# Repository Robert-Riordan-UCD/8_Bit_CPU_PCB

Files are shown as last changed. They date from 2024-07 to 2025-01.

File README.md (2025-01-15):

# 8-Bit PCB CPU

This is my version of [Ben Eaters 8-bit breadboard SAP-1 CPU](https://eater.net/8bit), converted to a PCB. I have made some minor changes as I could not find all of the components as listed in Ben's part list.

## Video of the computer running
https://youtube.com/shorts/QNcSWgcGv9o?si=QzoUVq9Kj8X1f4Rs

## Major Changes

### Random Access Memory

1. RAM IC's have been replaced with ATMega328-PU's. This should allow me to have persistant programs between power cycles.

## License

CERN Open Hardware Licence Version 2 - Permissive

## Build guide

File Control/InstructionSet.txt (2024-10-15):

0000 - NO OP
0001 - LDA
0010 - STA
0011 - LDB
0100 - ADD
0101 - SUB
0110 - JMP
0111 - JMPC
1000 - JMPZ
1001 - NO OP
1010 - NO OP
1011 - NO OP
1100 - NO OP
1101 - NO OP
1110 - OUT
1111 - HALT

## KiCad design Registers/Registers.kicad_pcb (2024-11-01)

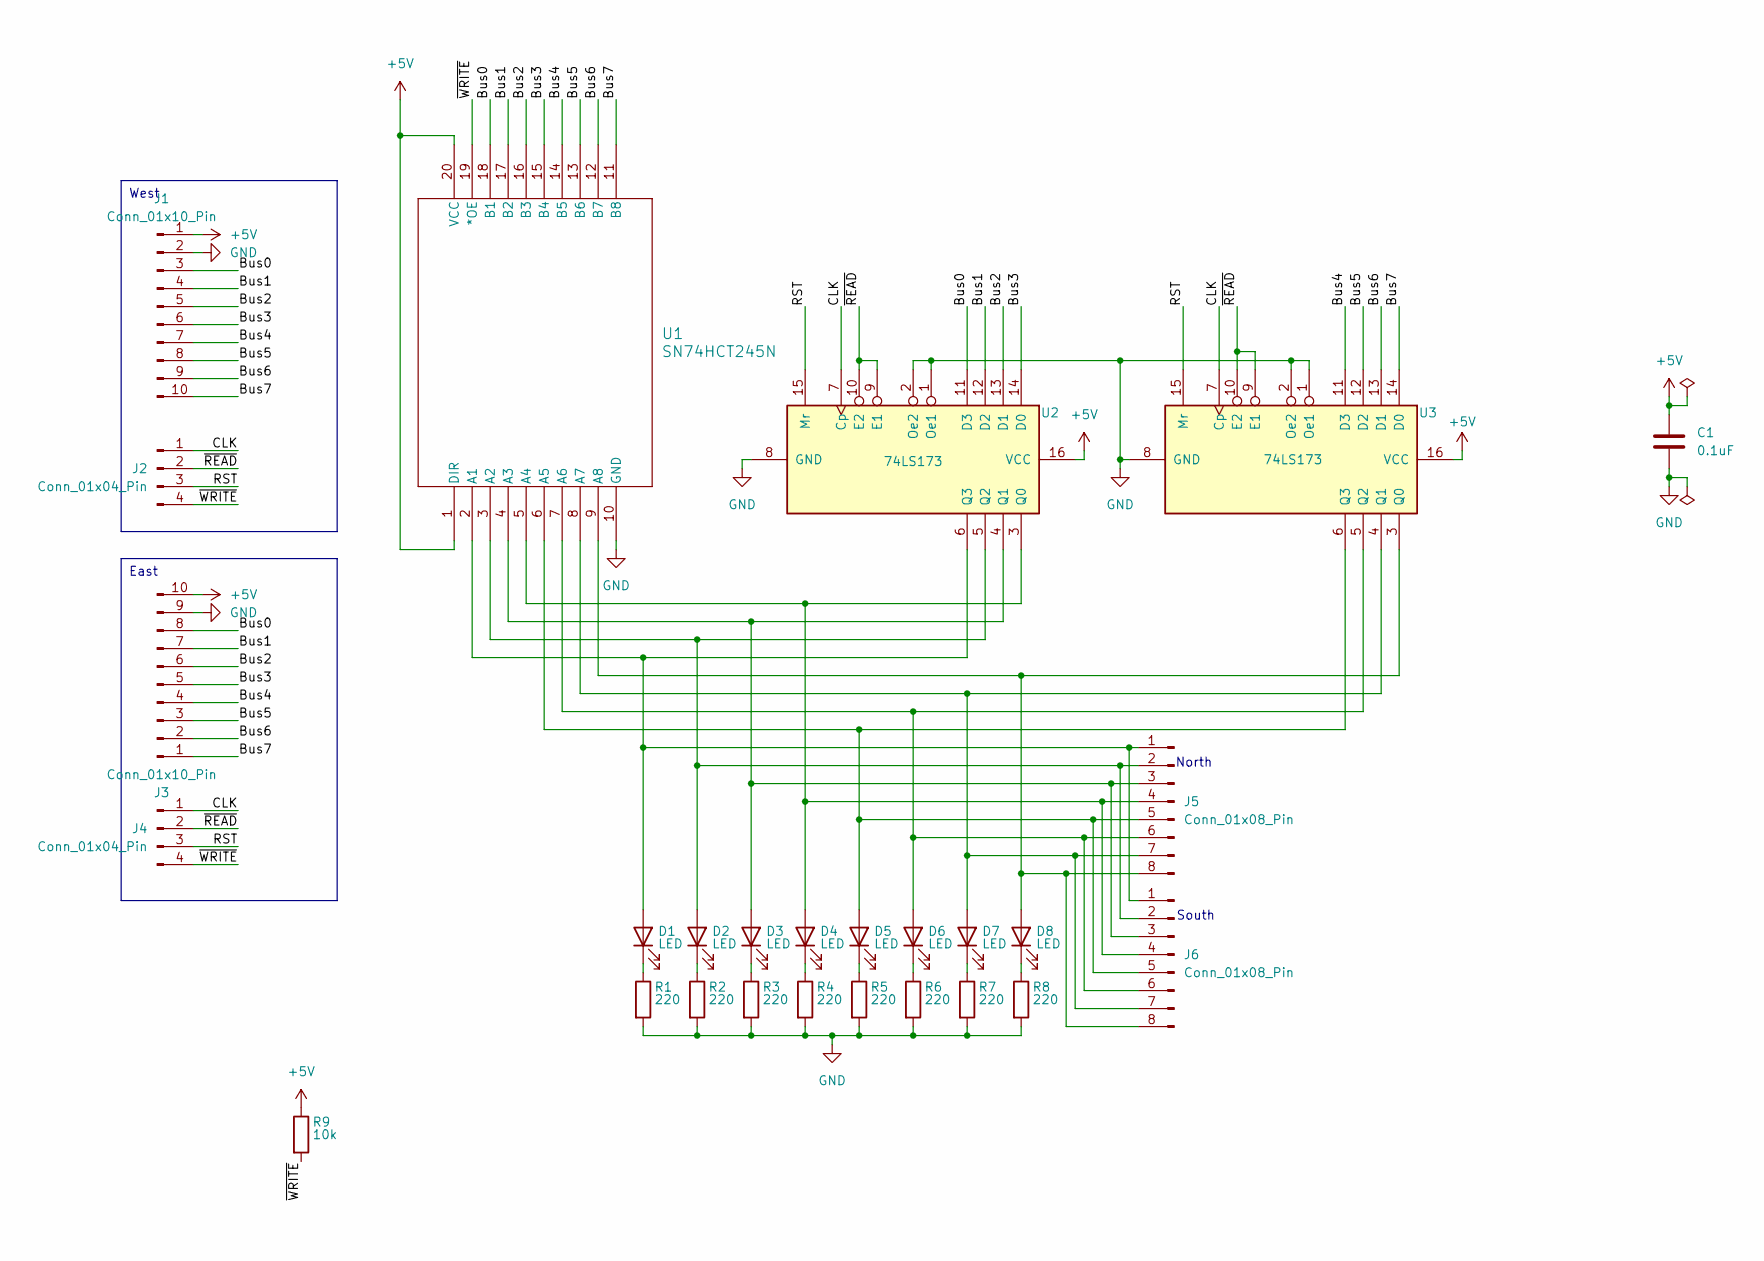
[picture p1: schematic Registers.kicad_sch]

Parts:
C1: 0.1uF; C_Disc_D5.0mm_W2.5mm_P2.50mm
D1, D2, D3, D4, D5, D6, D7, D8: LED; LED_D5.0mm
J1, J3: Conn_01x10_Pin; PinHeader_1x10_P2.54mm_Vertical
J2, J4: Conn_01x04_Pin; PinHeader_1x04_P2.54mm_Vertical
J5, J6: Conn_01x08_Pin; PinHeader_1x08_P2.54mm_Vertical
R1, R2, R3, R4, R5, R6, R7, R8: 220; CF_series_Resistors_THT
R9: 10k; CF_series_Resistors_THT
U1: SN74HCT245N; 8x_tristate_transceiver
U2, U3: 74LS173; DIP-16_W7.62mm

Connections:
+5V: C1.1, J1.1, J3.10, R9.1, U1.1 (DIR), U1.20 (VCC), U2.16 (VCC), U3.16 (VCC)
/Bus0: J1.3, J3.8, U1.18 (B1), U2.11 (D3)
/Bus1: J1.4, J3.7, U1.17 (B2), U2.12 (D2)
/Bus2: J1.5, J3.6, U1.16 (B3), U2.13 (D1)
/Bus3: J1.6, J3.5, U1.15 (B4), U2.14 (D0)
/Bus4: J1.7, J3.4, U1.14 (B5), U3.11 (D3)
/Bus5: J1.8, J3.3, U1.13 (B6), U3.12 (D2)
/Bus6: J1.9, J3.2, U1.12 (B7), U3.13 (D1)
/Bus7: J1.10, J3.1, U1.11 (B8), U3.14 (D0)
/CLK: J2.1, J4.1, U2.7 (Cp), U3.7 (Cp)
/RST: J2.3, J4.3, U2.15 (Mr), U3.15 (Mr)
/~READ: J2.2, J4.2, U2.9 (E1), U2.10 (E2), U3.9 (E1), U3.10 (E2)
/~WRITE: J2.4, J4.4, R9.2, U1.19 (*OE)
GND: C1.2, J1.2, J3.9, R1.2, R2.2, R3.2, R4.2, R5.2, R6.2, R7.2, R8.2, U1.10 (GND), U2.1 (Oe1), U2.2 (Oe2), U2.8 (GND), U3.1 (Oe1), U3.2 (Oe2), U3.8 (GND)
unnamed: D1.2 (A), J5.1, J6.1, U1.2 (A1), U2.6 (Q3)
unnamed: D1.1 (K), R1.1
unnamed: D2.2 (A), J5.2, J6.2, U1.3 (A2), U2.5 (Q2)
unnamed: D2.1 (K), R2.1
unnamed: D3.2 (A), J5.3, J6.3, U1.4 (A3), U2.4 (Q1)
unnamed: D3.1 (K), R3.1
unnamed: D4.2 (A), J5.4, J6.4, U1.5 (A4), U2.3 (Q0)
unnamed: D4.1 (K), R4.1
unnamed: D5.2 (A), J5.5, J6.5, U1.6 (A5), U3.6 (Q3)
unnamed: D5.1 (K), R5.1
unnamed: D6.2 (A), J5.6, J6.6, U1.7 (A6), U3.5 (Q2)
unnamed: D6.1 (K), R6.1
unnamed: D7.2 (A), J5.7, J6.7, U1.8 (A7), U3.4 (Q1)
unnamed: D7.1 (K), R7.1
unnamed: D8.2 (A), J5.8, J6.8, U1.9 (A8), U3.3 (Q0)
unnamed: D8.1 (K), R8.1

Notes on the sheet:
West
East
North
South

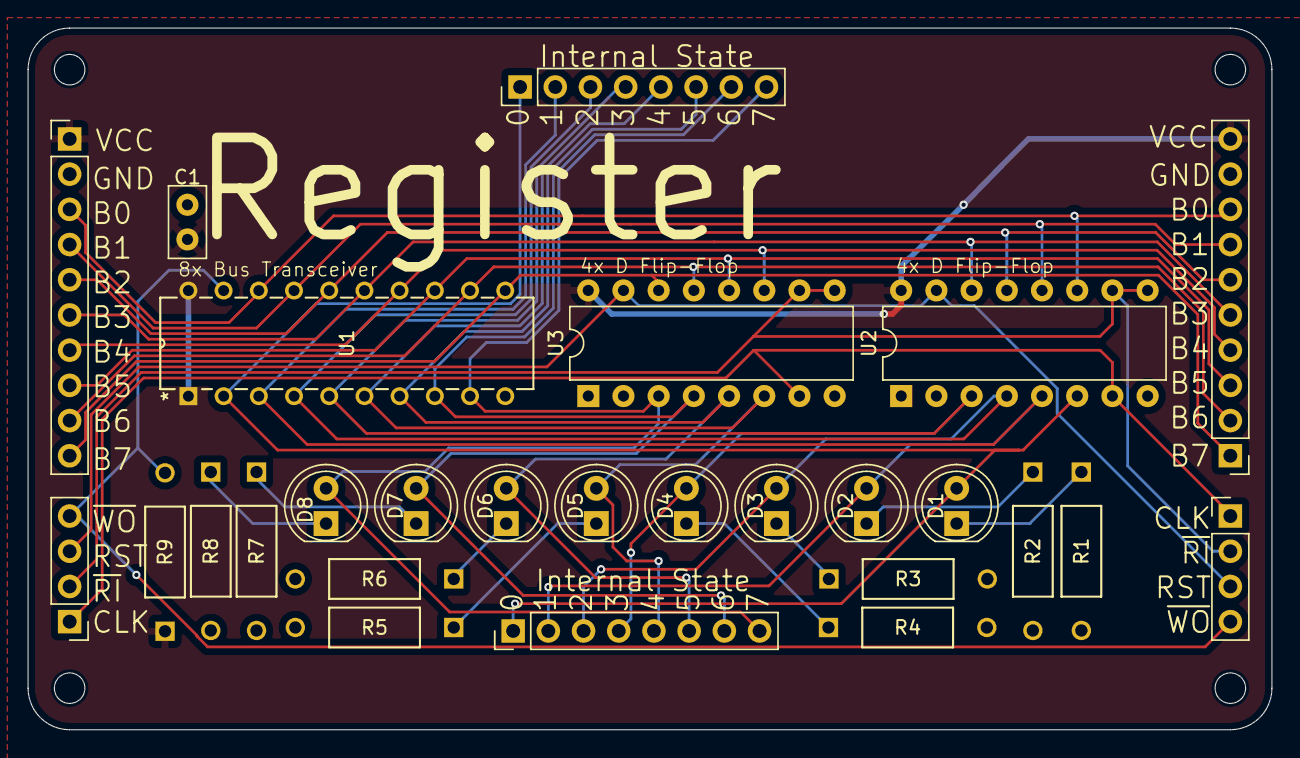
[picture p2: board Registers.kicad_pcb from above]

Board: 2 copper layers, 89.8 x 50.6 mm, 27 parts (0 on the bottom side), 30 nets.

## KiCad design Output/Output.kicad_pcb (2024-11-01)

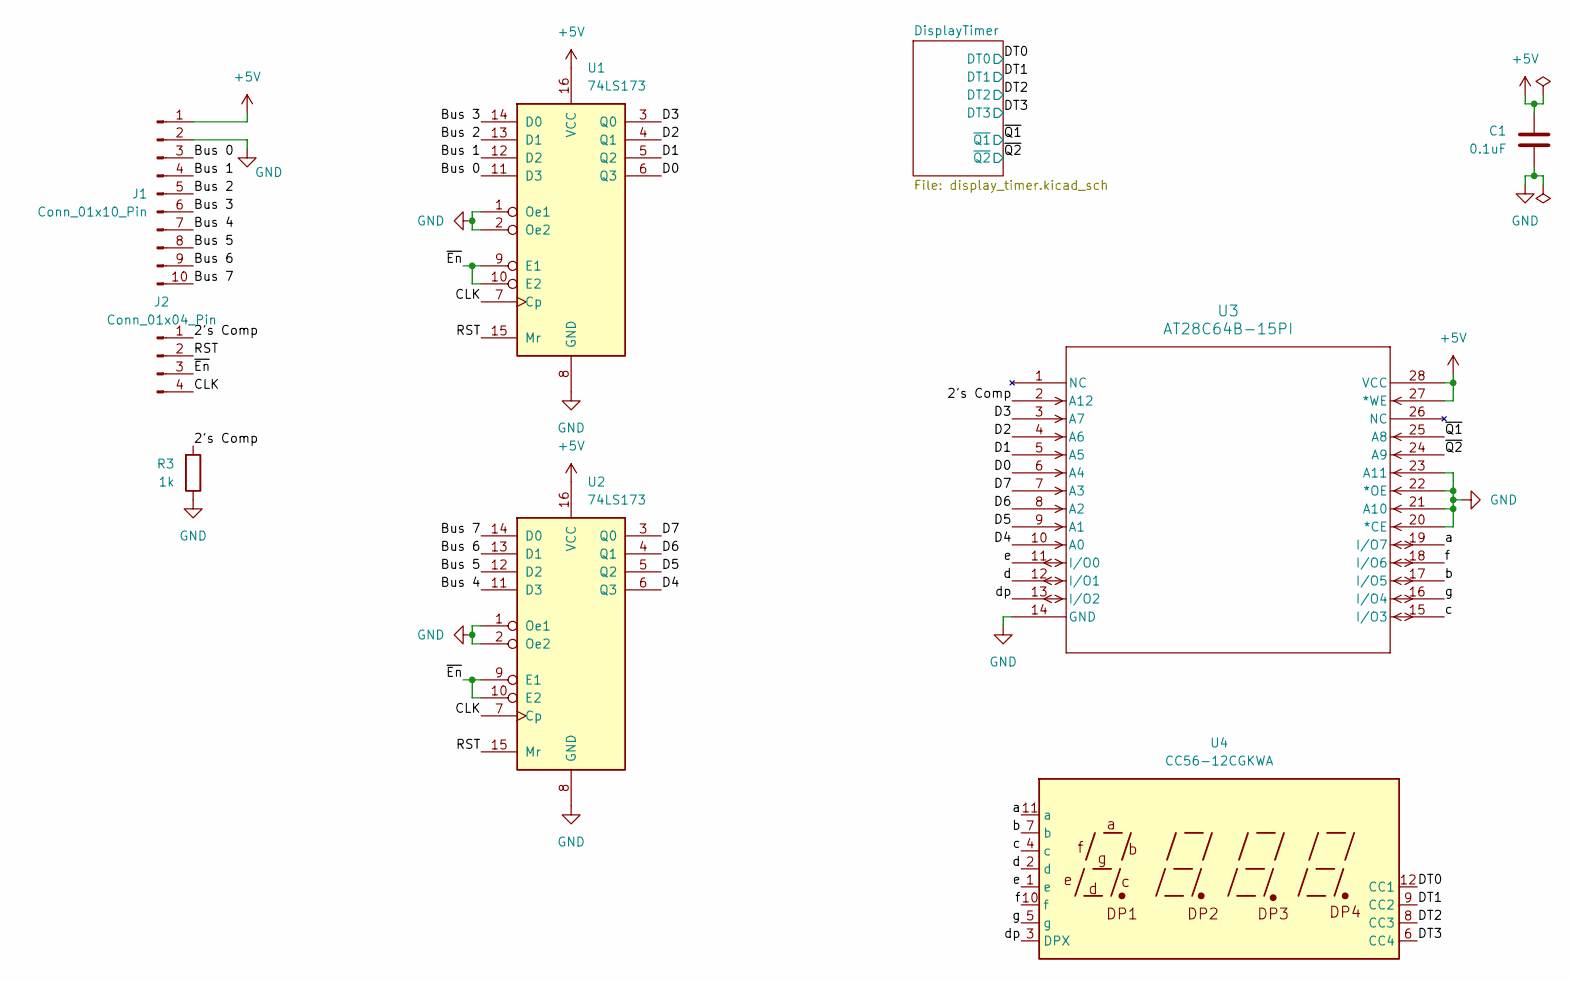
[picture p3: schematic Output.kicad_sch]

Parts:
C1: 0.1uF; C_Disc_D5.0mm_W2.5mm_P2.50mm
J1: Conn_01x10_Pin; PinHeader_1x10_P2.54mm_Vertical
J2: Conn_01x04_Pin; PinHeader_1x04_P2.54mm_Vertical
R3: 1k; CF_series_Resistors_THT
U1, U2: 74LS173; DIP-16_W7.62mm
U3: AT28C64B-15PI; eeprom
U4: CC56-12CGKWA; CA56-12CGKWA

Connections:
+5V: C1.1, J1.1, U1.16 (VCC), U2.16 (VCC), U3.27 (*WE), U3.28 (VCC); also elsewhere on the board
/2's Comp: J2.1, R3.2, U3.2 (A12)
/Bus 0: J1.3, U1.11 (D3)
/Bus 1: J1.4, U1.12 (D2)
/Bus 2: J1.5, U1.13 (D1)
/Bus 3: J1.6, U1.14 (D0)
/Bus 4: J1.7, U2.11 (D3)
/Bus 5: J1.8, U2.12 (D2)
/Bus 6: J1.9, U2.13 (D1)
/Bus 7: J1.10, U2.14 (D0)
/CLK: J2.4, U1.7 (Cp), U2.7 (Cp)
/D0: U1.6 (Q3), U3.6 (A4)
/D1: U1.5 (Q2), U3.5 (A5)
/D2: U1.4 (Q1), U3.4 (A6)
/D3: U1.3 (Q0), U3.3 (A7)
/D4: U2.6 (Q3), U3.10 (A0)
/D5: U2.5 (Q2), U3.9 (A1)
/D6: U2.4 (Q1), U3.8 (A2)
/D7: U2.3 (Q0), U3.7 (A3)
/DT0: U4.12 (CC1); also elsewhere on the board
/DT1: U4.9 (CC2); also elsewhere on the board
/DT2: U4.8 (CC3); also elsewhere on the board
/DT3: U4.6 (CC4); also elsewhere on the board
/RST: J2.2, U1.15 (Mr), U2.15 (Mr)
/a: U3.19 (I/O7), U4.11 (a)
/b: U3.17 (I/O5), U4.7 (b)
/c: U3.15 (I/O3), U4.4 (c)
/d: U3.12 (I/O1), U4.2 (d)
/dp: U3.13 (I/O2), U4.3 (DPX)
/e: U3.11 (I/O0), U4.1 (e)
/f: U3.18 (I/O6), U4.10 (f)
/g: U3.16 (I/O4), U4.5 (g)
/~En: J2.3, U1.9 (E1), U1.10 (E2), U2.9 (E1), U2.10 (E2)
/~Q1: U3.25 (A8); also elsewhere on the board
/~Q2: U3.24 (A9); also elsewhere on the board
GND: C1.2, J1.2, R3.1, U1.1 (Oe1), U1.2 (Oe2), U1.8 (GND), U2.1 (Oe1), U2.2 (Oe2), U2.8 (GND), U3.14 (GND), U3.20 (*CE), U3.21 (A10), U3.22 (*OE), U3.23 (A11); also elsewhere on the board

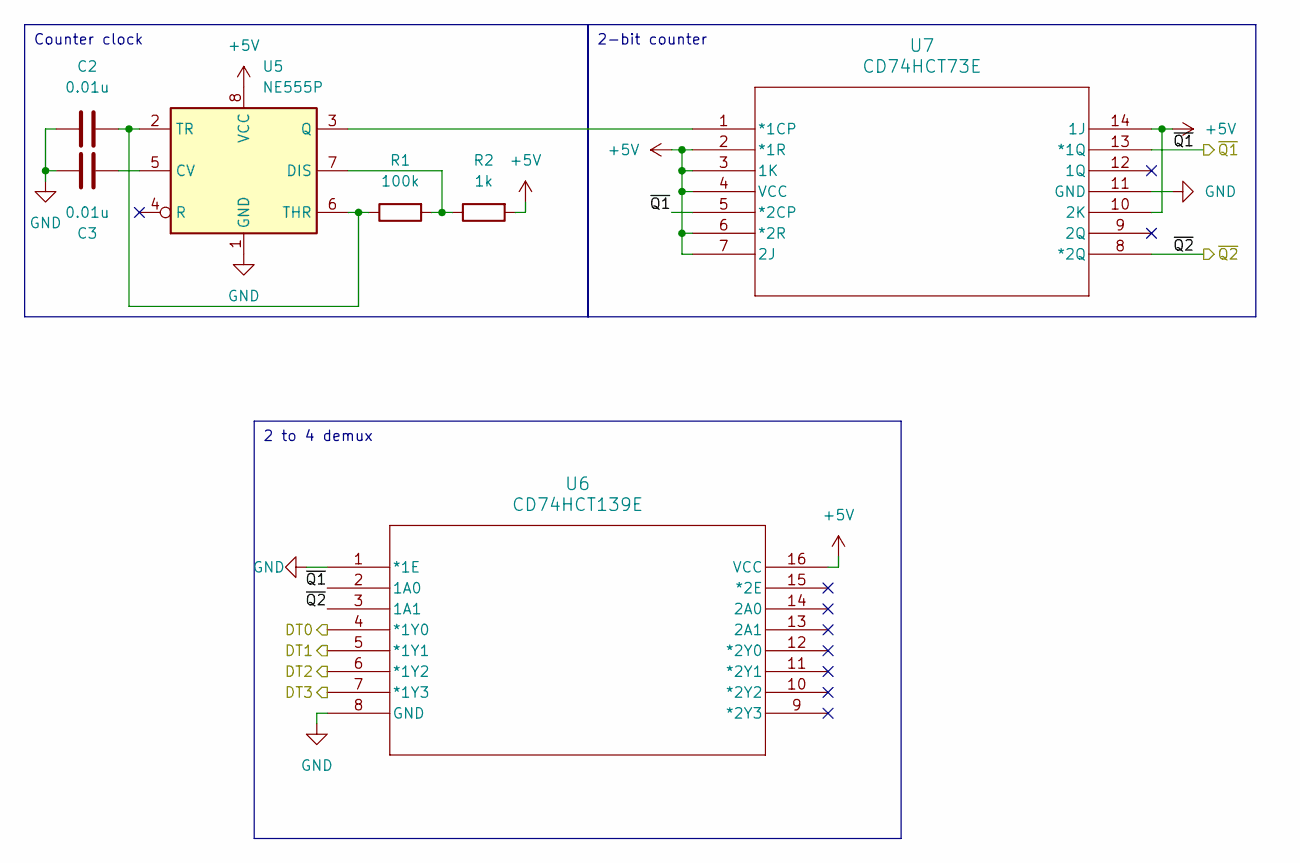
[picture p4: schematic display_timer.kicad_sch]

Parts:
C2, C3: 0.01u; C_Disc_D5.0mm_W2.5mm_P2.50mm
R1: 100k; CF_series_Resistors_THT
R2: 1k; CF_series_Resistors_THT
U5: NE555P; DIP-8_W7.62mm
U6: CD74HCT139E; 2x_2_to_4_demux
U7: CD74HCT73E; 2x_JK_FF

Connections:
+5V: R2.2, U5.8 (VCC), U6.16 (VCC), U7.2 (*1R), U7.3 (1K), U7.4 (VCC), U7.6 (*2R), U7.7 (2J), U7.10 (2K), U7.14 (1J); also elsewhere on the board
/DT0: U6.4 (*1Y0); also elsewhere on the board
/DT1: U6.5 (*1Y1); also elsewhere on the board
/DT2: U6.6 (*1Y2); also elsewhere on the board
/DT3: U6.7 (*1Y3); also elsewhere on the board
/~Q1: U6.2 (1A0), U7.5 (*2CP), U7.13 (*1Q); also elsewhere on the board
/~Q2: U6.3 (1A1), U7.8 (*2Q); also elsewhere on the board
GND: C2.1, C3.1, U5.1 (GND), U6.1 (*1E), U6.8 (GND), U7.11 (GND); also elsewhere on the board
unnamed: C3.2, U5.5 (CV)
unnamed: R1.2, R2.1, U5.7 (DIS)
unnamed: U5.3 (Q), U7.1 (*1CP)
unnamed: C2.2, R1.1, U5.2 (TR), U5.6 (THR)

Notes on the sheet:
2 to 4 demux
Counter clock
2-bit counter

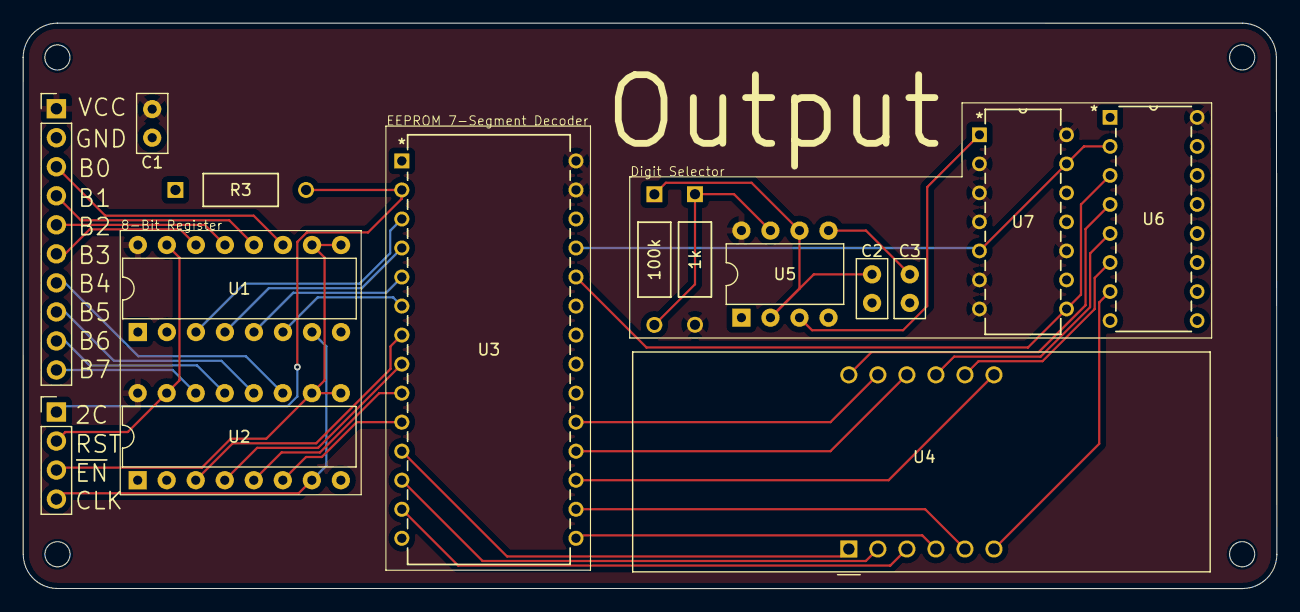
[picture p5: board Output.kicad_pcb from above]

Board: 2 copper layers, 109.7 x 49.5 mm, 15 parts (0 on the bottom side), 40 nets.

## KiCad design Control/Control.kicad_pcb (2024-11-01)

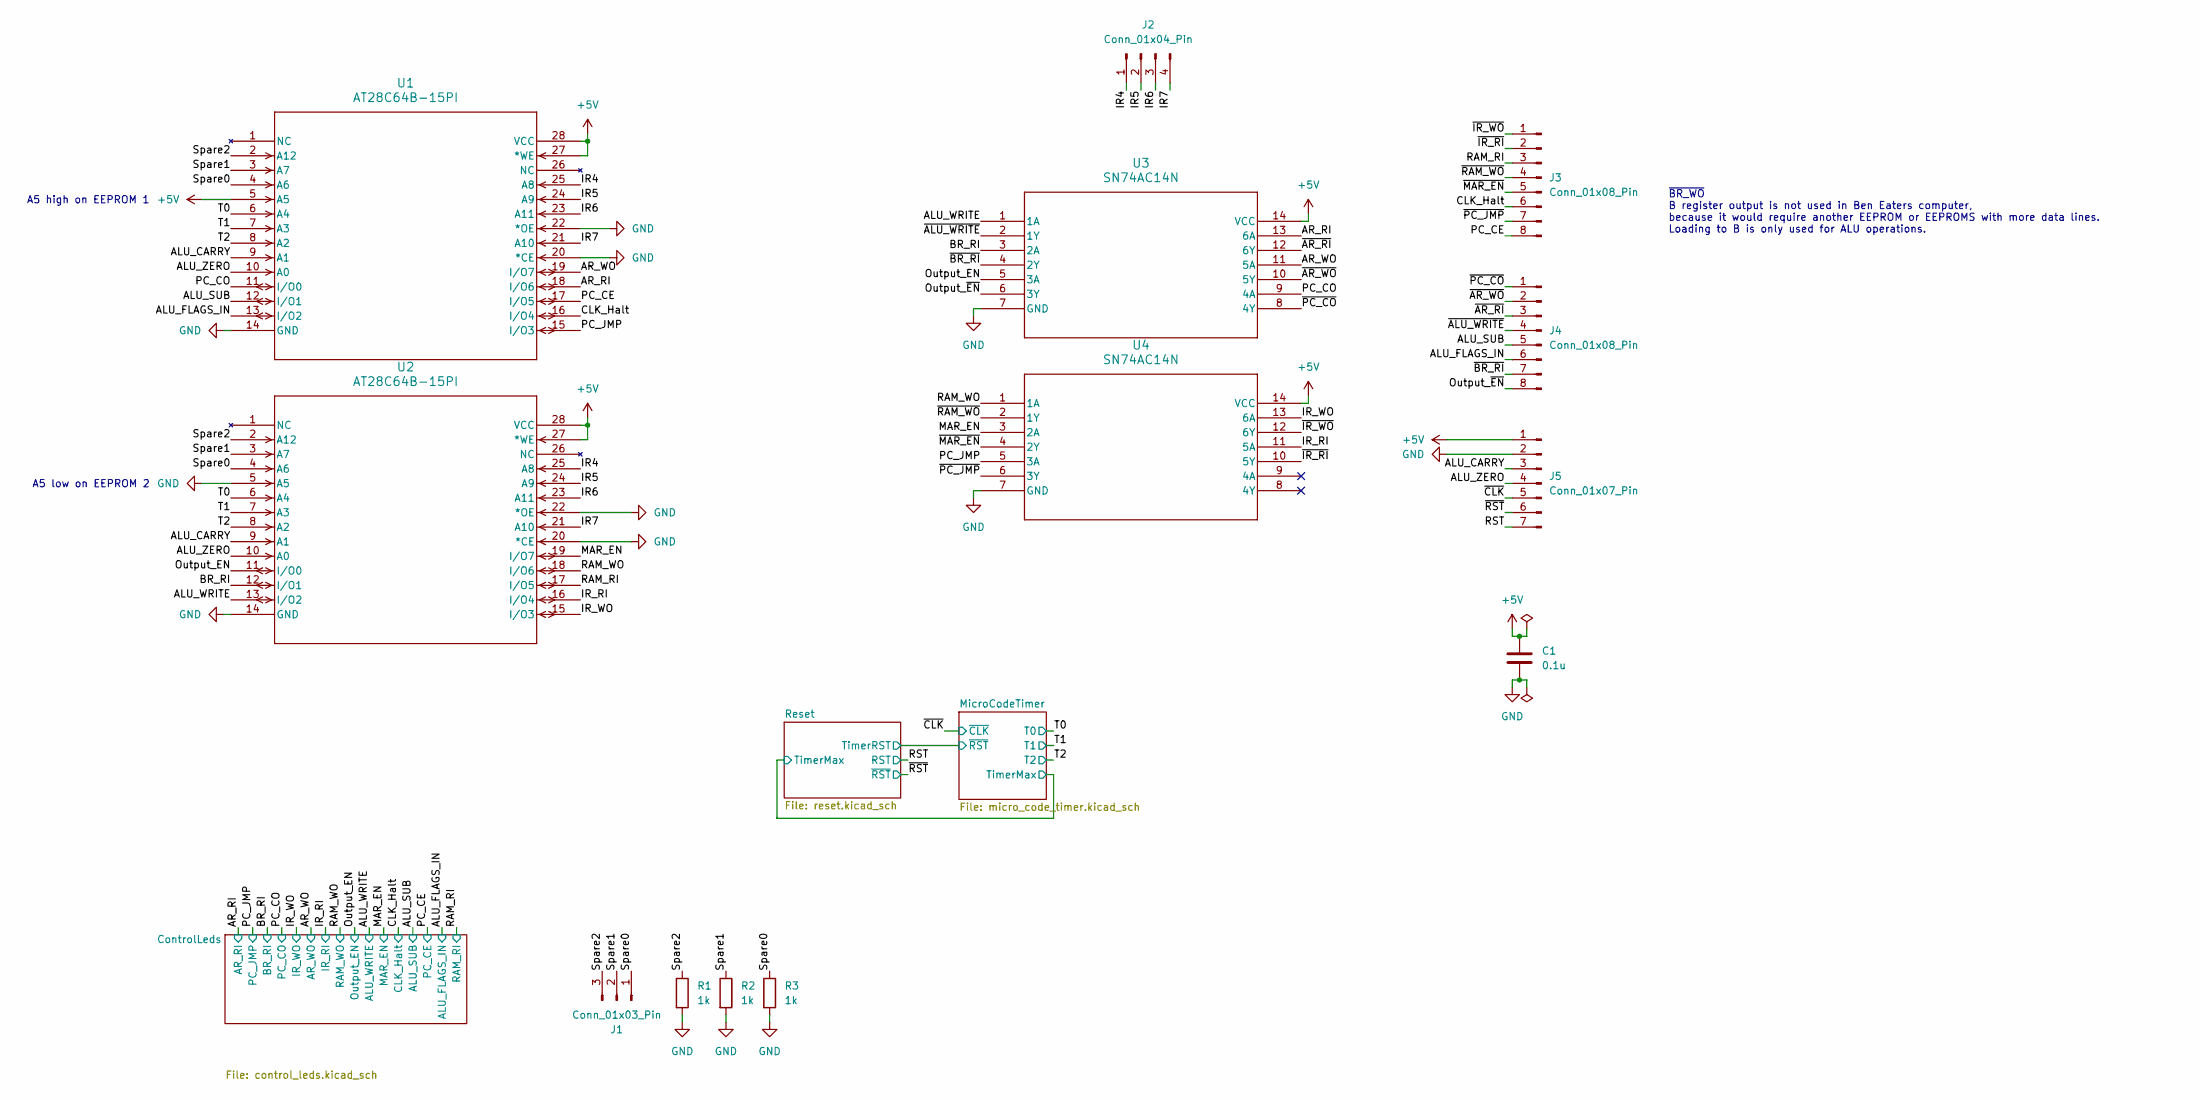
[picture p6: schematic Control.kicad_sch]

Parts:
C1: 0.1u; C_Disc_D5.0mm_W2.5mm_P2.50mm
J1: Conn_01x03_Pin; PinHeader_1x03_P2.54mm_Vertical
J2: Conn_01x04_Pin; PinHeader_1x04_P2.54mm_Vertical
J3, J4: Conn_01x08_Pin; PinHeader_1x08_P2.54mm_Vertical
J5: Conn_01x07_Pin; PinHeader_1x07_P2.54mm_Vertical
R1, R2, R3: 1k; CF_series_Resistors_THT
U1, U2: AT28C64B-15PI; eeprom
U3, U4: SN74AC14N; 6x_not

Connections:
+5V: C1.1, J5.1, U1.5 (A5), U1.27 (*WE), U1.28 (VCC), U2.27 (*WE), U2.28 (VCC), U3.14 (VCC), U4.14 (VCC); also elsewhere on the board
/ALU_CARRY: J5.3, U1.9 (A1), U2.9 (A1)
/ALU_FLAGS_IN: J4.6, U1.13 (I/O2); also elsewhere on the board
/ALU_SUB: J4.5, U1.12 (I/O1); also elsewhere on the board
/ALU_WRITE: U2.13 (I/O2), U3.1 (1A); also elsewhere on the board
/ALU_ZERO: J5.4, U1.10 (A0), U2.10 (A0)
/AR_RI: U1.18 (I/O6), U3.13 (6A); also elsewhere on the board
/AR_WO: U1.19 (I/O7), U3.11 (5A); also elsewhere on the board
/BR_RI: U2.12 (I/O1), U3.3 (2A); also elsewhere on the board
/CLK_Halt: J3.6, U1.16 (I/O4); also elsewhere on the board
/IR4: J2.1, U1.25 (A8), U2.25 (A8)
/IR5: J2.2, U1.24 (A9), U2.24 (A9)
/IR6: J2.3, U1.23 (A11), U2.23 (A11)
/IR7: J2.4, U1.21 (A10), U2.21 (A10)
/IR_RI: U2.16 (I/O4), U4.11 (5A); also elsewhere on the board
/IR_WO: U2.15 (I/O3), U4.13 (6A); also elsewhere on the board
/MAR_EN: U2.19 (I/O7), U4.3 (2A); also elsewhere on the board
/Output_EN: U2.11 (I/O0), U3.5 (3A); also elsewhere on the board
/Output_~EN: J4.8, U3.6 (3Y)
/PC_CE: J3.8, U1.17 (I/O5); also elsewhere on the board
/PC_CO: U1.11 (I/O0), U3.9 (4A); also elsewhere on the board
/PC_JMP: U1.15 (I/O3), U4.5 (3A); also elsewhere on the board
/RAM_RI: J3.3, U2.17 (I/O5); also elsewhere on the board
/RAM_WO: U2.18 (I/O6), U4.1 (1A); also elsewhere on the board
/RST: J5.7; also elsewhere on the board
/Spare0: J1.1, R3.1, U1.4 (A6), U2.4 (A6)
/Spare1: J1.2, R2.1, U1.3 (A7), U2.3 (A7)
/Spare2: J1.3, R1.1, U1.2 (A12), U2.2 (A12)
/T0: U1.6 (A4), U2.6 (A4); also elsewhere on the board
/T1: U1.7 (A3), U2.7 (A3); also elsewhere on the board
/T2: U1.8 (A2), U2.8 (A2); also elsewhere on the board
/~ALU_WRITE: J4.4, U3.2 (1Y)
/~AR_RI: J4.3, U3.12 (6Y)
/~AR_WO: J4.2, U3.10 (5Y)
/~BR_RI: J4.7, U3.4 (2Y)
/~CLK: J5.5; also elsewhere on the board
/~IR_RI: J3.2, U4.10 (5Y)
/~IR_WO: J3.1, U4.12 (6Y)
/~MAR_EN: J3.5, U4.4 (2Y)
/~PC_CO: J4.1, U3.8 (4Y)
/~PC_JMP: J3.7, U4.6 (3Y)
/~RAM_WO: J3.4, U4.2 (1Y)
/~RST: J5.6; also elsewhere on the board
GND: C1.2, J5.2, R1.2, R2.2, R3.2, U1.14 (GND), U1.20 (*CE), U1.22 (*OE), U2.5 (A5), U2.14 (GND), U2.20 (*CE), U2.22 (*OE), U3.7 (GND), U4.7 (GND); also elsewhere on the board

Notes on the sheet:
A5 high on EEPROM 1
~{BR_WO} B register output is not used in Ben Eaters computer, because it would require another EEPROM or EEPROMS with more data lines. Loading to B is only used for ALU operations.
A5 low on EEPROM 2

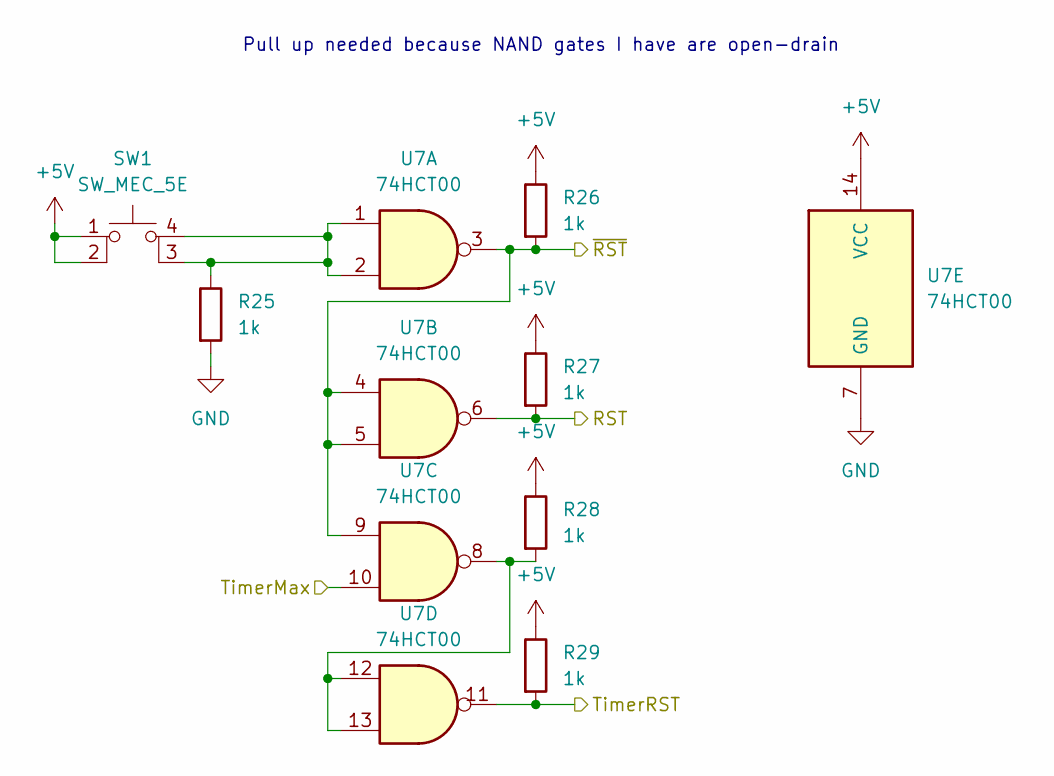
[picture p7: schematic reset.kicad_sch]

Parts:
R25, R26, R27, R28, R29: 1k; CF_series_Resistors_THT
SW1: SW_MEC_5E; tactile_switch
U7: 74HCT00; DIP-14_W7.62mm

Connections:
+5V: R26.1, R27.1, R28.1, R29.1, SW1.1, SW1.2, U7.14 (VCC); also elsewhere on the board
/MicroCodeTimer/TimerMax: U7.10; also elsewhere on the board
/MicroCodeTimer/~RST: R29.2, U7.11; also elsewhere on the board
/RST: R27.2, U7.6; also elsewhere on the board
/~RST: R26.2, U7.3, U7.4, U7.5, U7.9; also elsewhere on the board
GND: R25.2, U7.7 (GND); also elsewhere on the board
unnamed: R28.2, U7.8, U7.12, U7.13
unnamed: R25.1, SW1.3 (K), SW1.4 (A), U7.1, U7.2

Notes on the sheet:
Pull up needed because NAND gates I have are open-drain

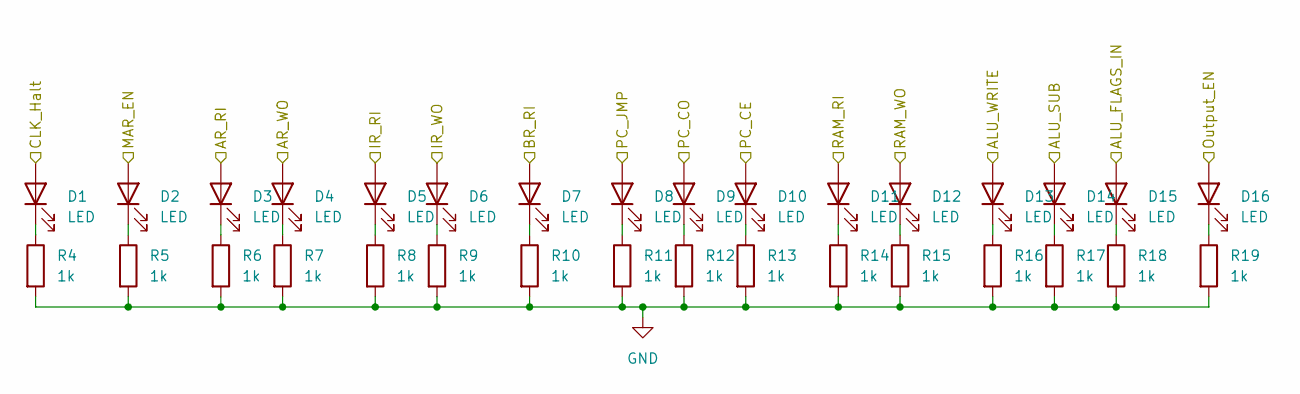
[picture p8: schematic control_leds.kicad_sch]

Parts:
D1, D2, D3, D4, D5, D6, D7, D8, D9, D10, D11, D12, D13, D14, D15, D16: LED; LED_D5.0mm
R4, R5, R6, R7, R8, R9, R10, R11, R12, R13, R14, R15, R16, R17, R18, R19: 1k; CF_series_Resistors_THT

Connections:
/ALU_FLAGS_IN: D15.2 (A); also elsewhere on the board
/ALU_SUB: D14.2 (A); also elsewhere on the board
/ALU_WRITE: D13.2 (A); also elsewhere on the board
/AR_RI: D3.2 (A); also elsewhere on the board
/AR_WO: D4.2 (A); also elsewhere on the board
/BR_RI: D7.2 (A); also elsewhere on the board
/CLK_Halt: D1.2 (A); also elsewhere on the board
/IR_RI: D5.2 (A); also elsewhere on the board
/IR_WO: D6.2 (A); also elsewhere on the board
/MAR_EN: D2.2 (A); also elsewhere on the board
/Output_EN: D16.2 (A); also elsewhere on the board
/PC_CE: D10.2 (A); also elsewhere on the board
/PC_CO: D9.2 (A); also elsewhere on the board
/PC_JMP: D8.2 (A); also elsewhere on the board
/RAM_RI: D11.2 (A); also elsewhere on the board
/RAM_WO: D12.2 (A); also elsewhere on the board
GND: R4.2, R5.2, R6.2, R7.2, R8.2, R9.2, R10.2, R11.2, R12.2, R13.2, R14.2, R15.2, R16.2, R17.2, R18.2, R19.2; also elsewhere on the board
unnamed: D1.1 (K), R4.1
unnamed: D2.1 (K), R5.1
unnamed: D3.1 (K), R6.1
unnamed: D4.1 (K), R7.1
unnamed: D5.1 (K), R8.1
unnamed: D6.1 (K), R9.1
unnamed: D7.1 (K), R10.1
unnamed: D8.1 (K), R11.1
unnamed: D9.1 (K), R12.1
unnamed: D10.1 (K), R13.1
unnamed: D11.1 (K), R14.1
unnamed: D12.1 (K), R15.1
unnamed: D13.1 (K), R16.1
unnamed: D14.1 (K), R17.1
unnamed: D15.1 (K), R18.1
unnamed: D16.1 (K), R19.1

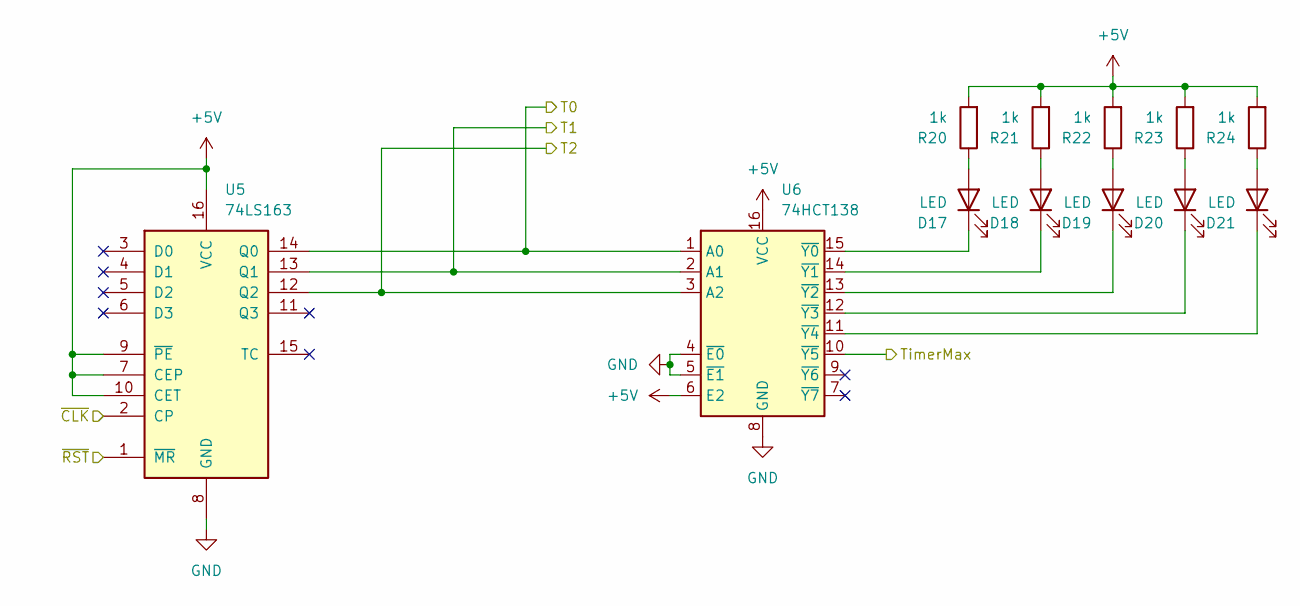
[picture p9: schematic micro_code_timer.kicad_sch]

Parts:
D17, D18, D19, D20, D21: LED; LED_D5.0mm
R20, R21, R22, R23, R24: 1k; CF_series_Resistors_THT
U5: 74LS163; DIP-16_W7.62mm
U6: 74HCT138; DIP-16_W7.62mm

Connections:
+5V: R20.2, R21.2, R22.2, R23.2, R24.2, U5.7 (CEP), U5.9 (~PE), U5.10 (CET), U5.16 (VCC), U6.6 (E2), U6.16 (VCC); also elsewhere on the board
/MicroCodeTimer/TimerMax: U6.10 (~Y5); also elsewhere on the board
/MicroCodeTimer/~RST: U5.1 (~MR); also elsewhere on the board
/T0: U5.14 (Q0), U6.1 (A0); also elsewhere on the board
/T1: U5.13 (Q1), U6.2 (A1); also elsewhere on the board
/T2: U5.12 (Q2), U6.3 (A2); also elsewhere on the board
/~CLK: U5.2 (CP); also elsewhere on the board
GND: U5.8 (GND), U6.4 (~E0), U6.5 (~E1), U6.8 (GND); also elsewhere on the board
unnamed: D17.2 (A), R20.1
unnamed: D17.1 (K), U6.15 (~Y0)
unnamed: D18.2 (A), R21.1
unnamed: D18.1 (K), U6.14 (~Y1)
unnamed: D19.2 (A), R22.1
unnamed: D19.1 (K), U6.13 (~Y2)
unnamed: D20.2 (A), R23.1
unnamed: D20.1 (K), U6.12 (~Y3)
unnamed: D21.2 (A), R24.1
unnamed: D21.1 (K), U6.11 (~Y4)

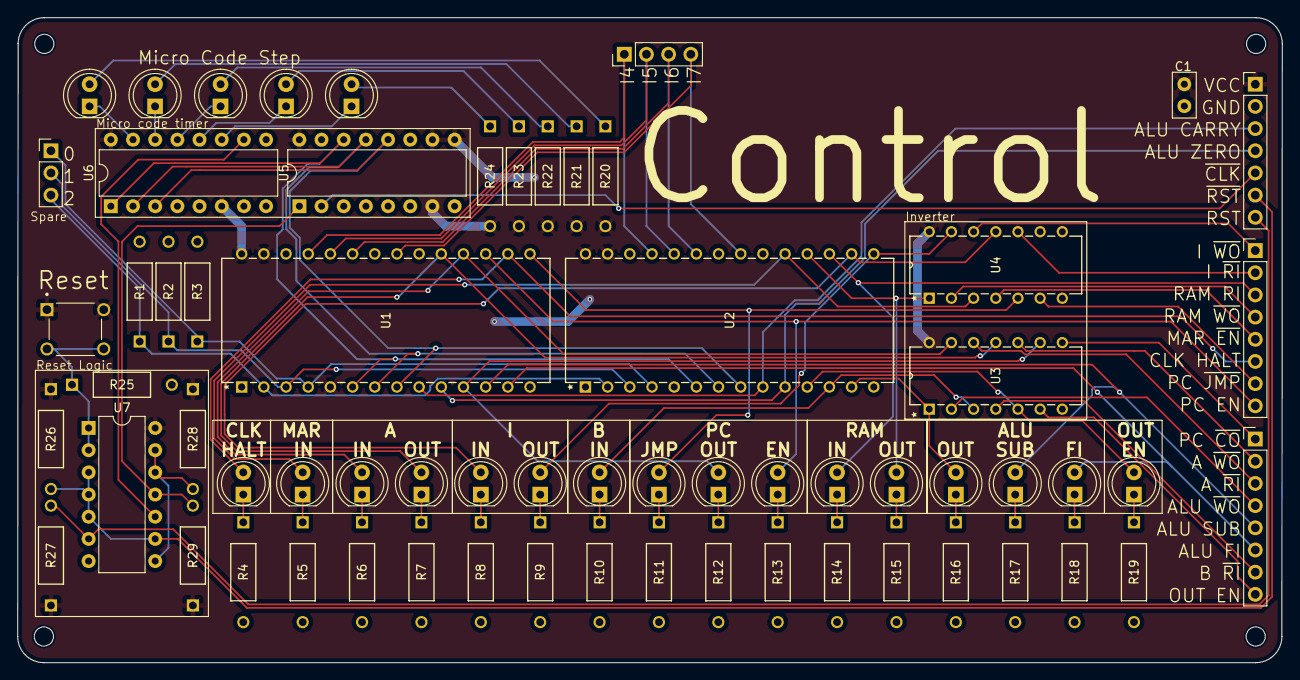
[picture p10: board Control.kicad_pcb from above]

Board: 2 copper layers, 144.8 x 73.9 mm, 64 parts (0 on the bottom side), 74 nets.

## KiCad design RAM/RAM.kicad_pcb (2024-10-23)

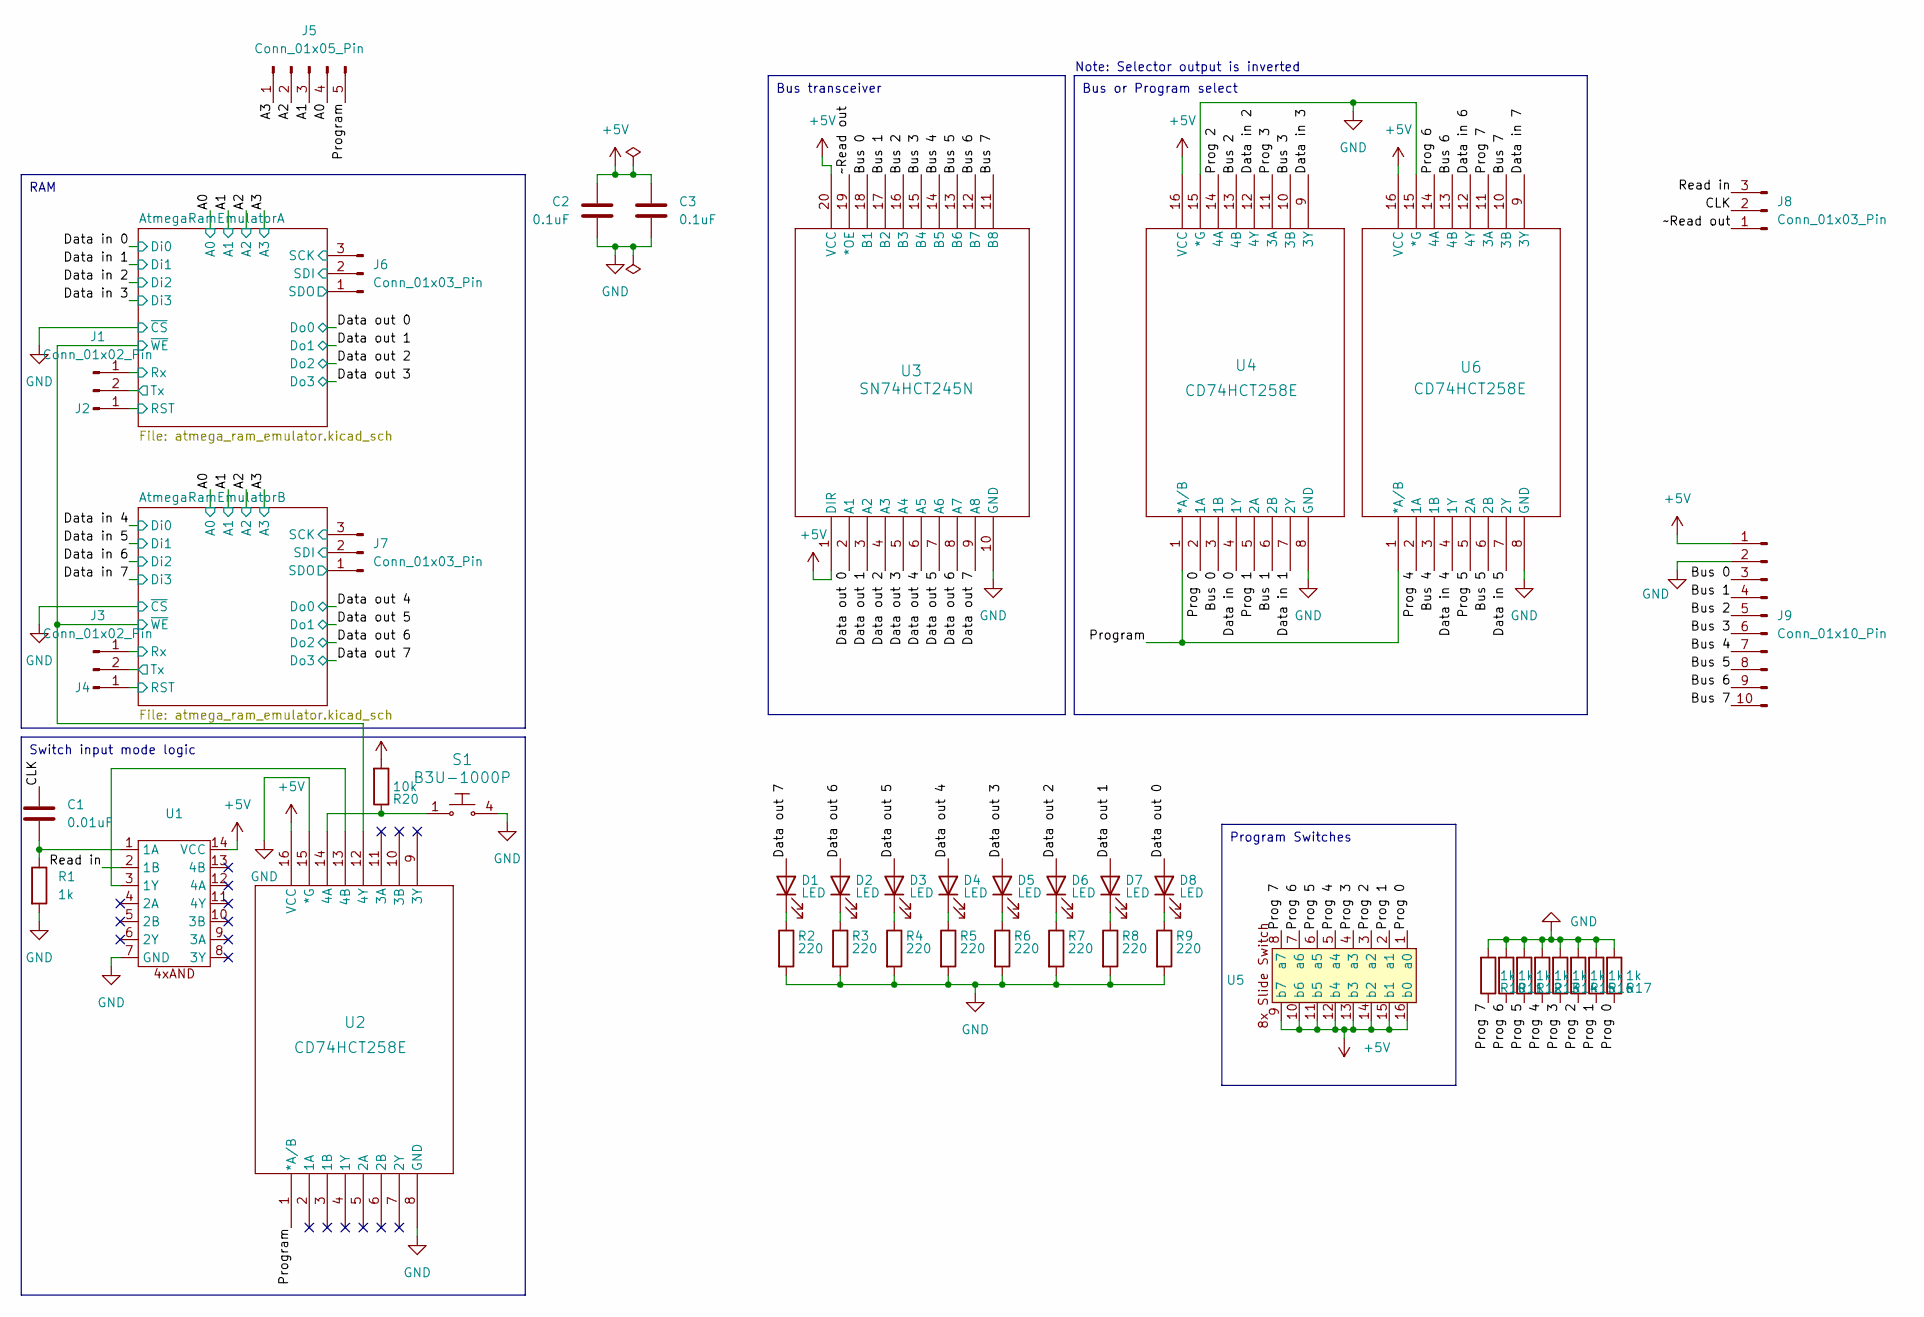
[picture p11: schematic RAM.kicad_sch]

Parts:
C1: 0.01uF; C_Disc_D5.0mm_W2.5mm_P2.50mm
C2, C3: 0.1uF; C_Disc_D5.0mm_W2.5mm_P2.50mm
D1, D2, D3, D4, D5, D6, D7, D8: LED; LED_D5.0mm
J1, J3: Conn_01x02_Pin; PinHeader_1x02_P2.54mm_Vertical
J2, J4: Conn_01x01_Pin; PinHeader_1x01_P2.54mm_Vertical
J5: Conn_01x05_Pin; PinHeader_1x05_P2.54mm_Vertical
J6, J7, J8: Conn_01x03_Pin; PinHeader_1x03_P2.54mm_Vertical
J9: Conn_01x10_Pin; PinHeader_1x10_P2.54mm_Vertical
R1, R10, R11, R12, R13, R14, R15, R16, R17: 1k; CF_series_Resistors_THT
R2, R3, R4, R5, R6, R7, R8, R9: 220; CF_series_Resistors_THT
R20: 10k; CF_series_Resistors_THT
S1: B3U-1000P; tactile_switch; MPN B3U-1000P; Digi-Key_PN SW1020CT-ND
U1: 4x_and
U2, U4, U6: CD74HCT258E; 2_to_1_selector
U3: SN74HCT245N; 8x_tristate_transceiver
U5: DIP-16_W7.62mm

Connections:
+5V: C2.1, C3.1, J9.1, R20.2, U1.14 (VCC), U2.16 (VCC), U3.1 (DIR), U3.20 (VCC), U4.16 (VCC), U5.9 (b7), U5.10 (b6), U5.11 (b5), U5.12 (b4), U5.13 (b3), U5.14 (b2), U5.15 (b1), U5.16 (b0), U6.16 (VCC); also elsewhere on the board
/A0: J5.4; also elsewhere on the board
/A1: J5.3; also elsewhere on the board
/A2: J5.2; also elsewhere on the board
/A3: J5.1; also elsewhere on the board
/AtmegaRamEmulatorA/RST: J2.1; also elsewhere on the board
/AtmegaRamEmulatorA/Rx: J1.1; also elsewhere on the board
/AtmegaRamEmulatorA/SCK: J6.3; also elsewhere on the board
/AtmegaRamEmulatorA/SDI: J6.2; also elsewhere on the board
/AtmegaRamEmulatorA/SDO: J6.1; also elsewhere on the board
/AtmegaRamEmulatorA/Tx: J1.2; also elsewhere on the board
/AtmegaRamEmulatorA/~WE: U2.12 (4Y); also elsewhere on the board
/AtmegaRamEmulatorB/RST: J4.1; also elsewhere on the board
/AtmegaRamEmulatorB/Rx: J3.1; also elsewhere on the board
/AtmegaRamEmulatorB/SCK: J7.3; also elsewhere on the board
/AtmegaRamEmulatorB/SDI: J7.2; also elsewhere on the board
/AtmegaRamEmulatorB/SDO: J7.1; also elsewhere on the board
/AtmegaRamEmulatorB/Tx: J3.2; also elsewhere on the board
/Bus 0: J9.3, U3.18 (B1), U4.3 (1B)
/Bus 1: J9.4, U3.17 (B2), U4.6 (2B)
/Bus 2: J9.5, U3.16 (B3), U4.13 (4B)
/Bus 3: J9.6, U3.15 (B4), U4.10 (3B)
/Bus 4: J9.7, U3.14 (B5), U6.3 (1B)
/Bus 5: J9.8, U3.13 (B6), U6.6 (2B)
/Bus 6: J9.9, U3.12 (B7), U6.13 (4B)
/Bus 7: J9.10, U3.11 (B8), U6.10 (3B)
/CLK: C1.1, J8.2
/Data in 0: U4.4 (1Y); also elsewhere on the board
/Data in 1: U4.7 (2Y); also elsewhere on the board
/Data in 2: U4.12 (4Y); also elsewhere on the board
/Data in 3: U4.9 (3Y); also elsewhere on the board
/Data in 4: U6.4 (1Y); also elsewhere on the board
/Data in 5: U6.7 (2Y); also elsewhere on the board
/Data in 6: U6.12 (4Y); also elsewhere on the board
/Data in 7: U6.9 (3Y); also elsewhere on the board
/Data out 0: D8.2 (A), U3.2 (A1); also elsewhere on the board
/Data out 1: D7.2 (A), U3.3 (A2); also elsewhere on the board
/Data out 2: D6.2 (A), U3.4 (A3); also elsewhere on the board
/Data out 3: D5.2 (A), U3.5 (A4); also elsewhere on the board
/Data out 4: D4.2 (A), U3.6 (A5); also elsewhere on the board
/Data out 5: D3.2 (A), U3.7 (A6); also elsewhere on the board
/Data out 6: D2.2 (A), U3.8 (A7); also elsewhere on the board
/Data out 7: D1.2 (A), U3.9 (A8); also elsewhere on the board
/Prog 0: R17.1, U4.2 (1A), U5.1 (a0)
/Prog 1: R16.1, U4.5 (2A), U5.2 (a1)
/Prog 2: R15.1, U4.14 (4A), U5.3 (a2)
/Prog 3: R14.1, U4.11 (3A), U5.4 (a3)
/Prog 4: R13.1, U5.5 (a4), U6.2 (1A)
/Prog 5: R12.1, U5.6 (a5), U6.5 (2A)
/Prog 6: R11.1, U5.7 (a6), U6.14 (4A)
/Prog 7: R10.1, U5.8 (a7), U6.11 (3A)
/Program: J5.5, U2.1 (*A/B), U4.1 (*A/B), U6.1 (*A/B)
/Read in: J8.3, U1.2 (1B)
/~Read out: J8.1, U3.19 (*OE)
GND: C2.2, C3.2, J9.2, R1.2, R2.2, R3.2, R4.2, R5.2, R6.2, R7.2, R8.2, R9.2, R10.2, R11.2, R12.2, R13.2, R14.2, R15.2, R16.2, R17.2, S1.4, U1.7 (GND), U2.8 (GND), U2.15 (*G), U3.10 (GND), U4.8 (GND), U4.15 (*G), U6.8 (GND), U6.15 (*G); also elsewhere on the board
unnamed: D1.1 (K), R2.1
unnamed: D2.1 (K), R3.1
unnamed: D3.1 (K), R4.1
unnamed: D4.1 (K), R5.1
unnamed: D5.1 (K), R6.1
unnamed: D6.1 (K), R7.1
unnamed: D7.1 (K), R8.1
unnamed: D8.1 (K), R9.1
unnamed: C1.2, R1.1, U1.1 (1A)
unnamed: U1.3 (1Y), U2.13 (4B)
unnamed: R20.1, S1.1, U2.14 (4A)

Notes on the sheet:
Program Switches
Switch input mode logic
Bus or Program select
RAM
Bus transceiver
Note: Selector output is inverted

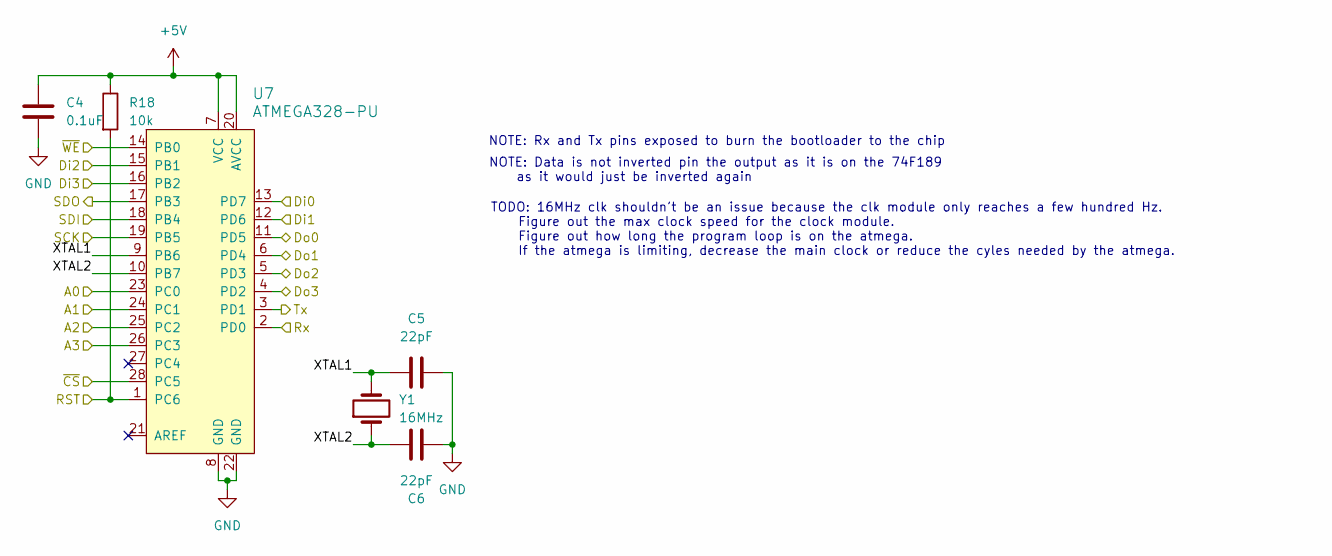
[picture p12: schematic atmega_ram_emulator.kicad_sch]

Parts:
C4: 0.1uF; Cp_2mm_pin_spacing
C5, C6: 22pF; C_Disc_D5.0mm_W2.5mm_P2.50mm
R18: 10k; CF_series_Resistors_THT
U7: ATMEGA328-PU; DIP787W46P254L3467H508Q28; MPN ATMEGA328-PU; Digi-Key_PN ATMEGA328-PU-ND
Y1: 16MHz; 16MHzCrystalOscillator

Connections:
+5V: C4.1, R18.1, U7.7 (VCC), U7.20 (AVCC); also elsewhere on the board
/A0: U7.23 (PC0); also elsewhere on the board
/A1: U7.24 (PC1); also elsewhere on the board
/A2: U7.25 (PC2); also elsewhere on the board
/A3: U7.26 (PC3); also elsewhere on the board
/AtmegaRamEmulatorA/RST: R18.2, U7.1 (PC6); also elsewhere on the board
/AtmegaRamEmulatorA/Rx: U7.2 (PD0); also elsewhere on the board
/AtmegaRamEmulatorA/SCK: U7.19 (PB5); also elsewhere on the board
/AtmegaRamEmulatorA/SDI: U7.18 (PB4); also elsewhere on the board
/AtmegaRamEmulatorA/SDO: U7.17 (PB3); also elsewhere on the board
/AtmegaRamEmulatorA/Tx: U7.3 (PD1); also elsewhere on the board
/AtmegaRamEmulatorA/XTAL1: C5.1, U7.9 (PB6), Y1.2
/AtmegaRamEmulatorA/XTAL2: C6.2, U7.10 (PB7), Y1.1
/AtmegaRamEmulatorA/~WE: U7.14 (PB0); also elsewhere on the board
/Data in 0: U7.13 (PD7); also elsewhere on the board
/Data in 1: U7.12 (PD6); also elsewhere on the board
/Data in 2: U7.15 (PB1); also elsewhere on the board
/Data in 3: U7.16 (PB2); also elsewhere on the board
/Data out 0: U7.11 (PD5); also elsewhere on the board
/Data out 1: U7.6 (PD4); also elsewhere on the board
/Data out 2: U7.5 (PD3); also elsewhere on the board
/Data out 3: U7.4 (PD2); also elsewhere on the board
GND: C4.2, C5.2, C6.1, U7.8 (GND), U7.22 (GND), U7.28 (PC5); also elsewhere on the board

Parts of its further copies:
C7: 0.1uF; Cp_2mm_pin_spacing
C8, C9: 22pF; C_Disc_D5.0mm_W2.5mm_P2.50mm
R19: 10k; CF_series_Resistors_THT
U8: ATMEGA328-PU; DIP787W46P254L3467H508Q28; MPN ATMEGA328-PU; Digi-Key_PN ATMEGA328-PU-ND
Y2: 16MHz; 16MHzCrystalOscillator

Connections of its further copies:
+5V: C7.1, R19.1, U8.7 (VCC), U8.20 (AVCC); also elsewhere on the board
/A0: U8.23 (PC0); also elsewhere on the board
/A1: U8.24 (PC1); also elsewhere on the board
/A2: U8.25 (PC2); also elsewhere on the board
/A3: U8.26 (PC3); also elsewhere on the board
/AtmegaRamEmulatorA/~WE: U8.14 (PB0); also elsewhere on the board
/AtmegaRamEmulatorB/RST: R19.2, U8.1 (PC6); also elsewhere on the board
/AtmegaRamEmulatorB/Rx: U8.2 (PD0); also elsewhere on the board
/AtmegaRamEmulatorB/SCK: U8.19 (PB5); also elsewhere on the board
/AtmegaRamEmulatorB/SDI: U8.18 (PB4); also elsewhere on the board
/AtmegaRamEmulatorB/SDO: U8.17 (PB3); also elsewhere on the board
/AtmegaRamEmulatorB/Tx: U8.3 (PD1); also elsewhere on the board
/AtmegaRamEmulatorB/XTAL1: C8.1, U8.9 (PB6), Y2.2
/AtmegaRamEmulatorB/XTAL2: C9.2, U8.10 (PB7), Y2.1
/Data in 4: U8.13 (PD7); also elsewhere on the board
/Data in 5: U8.12 (PD6); also elsewhere on the board
/Data in 6: U8.15 (PB1); also elsewhere on the board
/Data in 7: U8.16 (PB2); also elsewhere on the board
/Data out 4: U8.11 (PD5); also elsewhere on the board
/Data out 5: U8.6 (PD4); also elsewhere on the board
/Data out 6: U8.5 (PD3); also elsewhere on the board
/Data out 7: U8.4 (PD2); also elsewhere on the board
GND: C7.2, C8.2, C9.1, U8.8 (GND), U8.22 (GND), U8.28 (PC5); also elsewhere on the board

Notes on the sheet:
NOTE: Rx and Tx pins exposed to burn the bootloader to the chip
TODO: 16MHz clk shouldn't be an issue because the clk module only reaches a few hundred Hz. Figure out the max clock speed for the clock module. Figure out how long the program loop is on the atmega. If the atmega is limiting, decrease the main clock or reduce the cyles needed by the atmega.
NOTE: Data is not inverted pin the output as it is on the 74F189 as it would just be inverted again


Board: 2 copper layers, 133.0 x 58.5 mm, 57 parts (0 on the bottom side), 70 nets.

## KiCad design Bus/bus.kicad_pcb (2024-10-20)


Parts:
D1, D2, D3, D4, D5, D6, D7, D8: LED; LED_D5.0mm
R1, R2, R3, R4, R5, R6, R7, R8: 10k; CF_series_Resistors_THT
R9, R10, R11, R12, R13, R14, R15, R16: 220; CF_series_Resistors_THT

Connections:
/B0: D1.2 (A), R8.1; also elsewhere on the board
/B1: D2.2 (A), R7.1; also elsewhere on the board
/B2: D3.2 (A), R6.1; also elsewhere on the board
/B3: D4.2 (A), R5.1; also elsewhere on the board
/B4: D5.2 (A), R4.1; also elsewhere on the board
/B5: D6.2 (A), R3.1; also elsewhere on the board
/B6: D7.2 (A), R2.1; also elsewhere on the board
/B7: D8.2 (A), R1.1; also elsewhere on the board
GND: R1.2, R2.2, R3.2, R4.2, R5.2, R6.2, R7.2, R8.2, R9.2, R10.2, R11.2, R12.2, R13.2, R14.2, R15.2, R16.2; also elsewhere on the board
unnamed: D1.1 (K), R9.1
unnamed: D2.1 (K), R10.1
unnamed: D3.1 (K), R11.1
unnamed: D4.1 (K), R12.1
unnamed: D5.1 (K), R13.1
unnamed: D6.1 (K), R14.1
unnamed: D7.1 (K), R15.1
unnamed: D8.1 (K), R16.1


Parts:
J23: USB_C_Receptacle_PowerOnly_6P; USB_C_Receptacle_GCT_USB4085
J24: Conn_02x03_Counter_Clockwise; PinHeader_2x03_P2.54mm_Vertical
R17, R18: 5.1k; CF_series_Resistors_THT

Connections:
+5V: J23.A9 (VBUS), J23.B9 (VBUS), J24.1, J24.3 (Pin_2), J24.5 (Pin_3); also elsewhere on the board
GND: J23.A12 (GND), J23.B12 (GND), J23.S1 (SHIELD), J24.2 (Pin_4), J24.4 (Pin_5), J24.6, R17.2, R18.2; also elsewhere on the board
unnamed: J23.A5 (CC1), R17.1
unnamed: J23.B5 (CC2), R18.1


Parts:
J15: Conn_01x06_Pin; PinHeader_1x06_P2.54mm_Vertical
J16: Conn_01x03_Pin; PinHeader_1x03_P2.54mm_Vertical

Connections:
+5V: J15.1; also elsewhere on the board
/B0: J15.3; also elsewhere on the board
/B1: J15.4; also elsewhere on the board
/B2: J15.5; also elsewhere on the board
/B3: J15.6; also elsewhere on the board
/CLK: J16.3; also elsewhere on the board
/MAR_~EN: J16.1; also elsewhere on the board
/RST: J16.2; also elsewhere on the board
GND: J15.2; also elsewhere on the board


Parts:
J4: Conn_01x10_Pin; PinHeader_1x10_P2.54mm_Vertical
J5: Conn_01x04_Pin; PinHeader_1x04_P2.54mm_Vertical

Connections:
+5V: J4.1, J5.1; also elsewhere on the board
/B0: J4.3; also elsewhere on the board
/B1: J4.4; also elsewhere on the board
/B2: J4.5; also elsewhere on the board
/B3: J4.6; also elsewhere on the board
/B4: J4.7; also elsewhere on the board
/B5: J4.8; also elsewhere on the board
/B6: J4.9; also elsewhere on the board
/B7: J4.10; also elsewhere on the board
/BR_~READ: J5.3; also elsewhere on the board
/CLK: J5.4; also elsewhere on the board
/RST: J5.2; also elsewhere on the board
GND: J4.2; also elsewhere on the board

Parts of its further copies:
J2: Conn_01x10_Pin; PinHeader_1x10_P2.54mm_Vertical
J3: Conn_01x04_Pin; PinHeader_1x04_P2.54mm_Vertical

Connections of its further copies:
+5V: J2.1; also elsewhere on the board
/AR_~READ: J3.3; also elsewhere on the board
/AR_~WRITE: J3.1; also elsewhere on the board
/B0: J2.3; also elsewhere on the board
/B1: J2.4; also elsewhere on the board
/B2: J2.5; also elsewhere on the board
/B3: J2.6; also elsewhere on the board
/B4: J2.7; also elsewhere on the board
/B5: J2.8; also elsewhere on the board
/B6: J2.9; also elsewhere on the board
/B7: J2.10; also elsewhere on the board
/CLK: J3.4; also elsewhere on the board
/RST: J3.2; also elsewhere on the board
GND: J2.2; also elsewhere on the board


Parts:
J1: Conn_01x05_Pin; PinHeader_1x05_P2.54mm_Vertical

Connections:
+5V: J1.1; also elsewhere on the board
/CLK: J1.3; also elsewhere on the board
/HALT: J1.5; also elsewhere on the board
/~CLK: J1.4; also elsewhere on the board
GND: J1.2; also elsewhere on the board


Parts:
J17: Conn_01x10_Pin; PinHeader_1x10_P2.54mm_Vertical
J18: Conn_01x03_Pin; PinHeader_1x03_P2.54mm_Vertical

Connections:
+5V: J17.1; also elsewhere on the board
/B0: J17.3; also elsewhere on the board
/B1: J17.4; also elsewhere on the board
/B2: J17.5; also elsewhere on the board
/B3: J17.6; also elsewhere on the board
/B4: J17.7; also elsewhere on the board
/B5: J17.8; also elsewhere on the board
/B6: J17.9; also elsewhere on the board
/B7: J17.10; also elsewhere on the board
/CLK: J18.2; also elsewhere on the board
/RAM_RI: J18.3; also elsewhere on the board
/RAM_~WO: J18.1; also elsewhere on the board
GND: J17.2; also elsewhere on the board


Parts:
J19: Conn_01x10_Pin; PinHeader_1x10_P2.54mm_Vertical
J20: Conn_01x03_Pin; PinHeader_1x03_P2.54mm_Vertical

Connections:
+5V: J19.1; also elsewhere on the board
/B0: J19.3; also elsewhere on the board
/B1: J19.4; also elsewhere on the board
/B2: J19.5; also elsewhere on the board
/B3: J19.6; also elsewhere on the board
/B4: J19.7; also elsewhere on the board
/B5: J19.8; also elsewhere on the board
/B6: J19.9; also elsewhere on the board
/B7: J19.10; also elsewhere on the board
/CLK: J20.1; also elsewhere on the board
/~RST: J20.3; also elsewhere on the board
/~CLK: J20.2; also elsewhere on the board
GND: J19.2; also elsewhere on the board


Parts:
J10: Conn_01x10_Pin; PinHeader_1x10_P2.54mm_Vertical
J11: Conn_01x05_Pin; PinHeader_1x05_P2.54mm_Vertical

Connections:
+5V: J10.1; also elsewhere on the board
/B0: J10.10; also elsewhere on the board
/B1: J10.9; also elsewhere on the board
/B2: J10.8; also elsewhere on the board
/B3: J10.7; also elsewhere on the board
/B4: J10.6; also elsewhere on the board
/B5: J10.5; also elsewhere on the board
/B6: J10.4; also elsewhere on the board
/B7: J10.3; also elsewhere on the board
/CLK: J11.3; also elsewhere on the board
/PC_CE: J11.2; also elsewhere on the board
/PC_~CO: J11.5; also elsewhere on the board
/PC_~JMP: J11.1; also elsewhere on the board
/~RST: J11.4; also elsewhere on the board
GND: J10.2; also elsewhere on the board

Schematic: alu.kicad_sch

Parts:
J8: Conn_01x10_Pin; PinHeader_1x10_P2.54mm_Vertical
J9: Conn_01x07_Pin; PinHeader_1x07_P2.54mm_Vertical

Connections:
+5V: J8.1; also elsewhere on the board
/ALU_CARRY: J9.6; also elsewhere on the board
/ALU_FI: J9.5; also elsewhere on the board
/ALU_SUB: J9.2; also elsewhere on the board
/ALU_ZERO: J9.7; also elsewhere on the board
/ALU_~WRITE: J9.1; also elsewhere on the board
/B0: J8.10; also elsewhere on the board
/B1: J8.9; also elsewhere on the board
/B2: J8.8; also elsewhere on the board
/B3: J8.7; also elsewhere on the board
/B4: J8.6; also elsewhere on the board
/B5: J8.5; also elsewhere on the board
/B6: J8.4; also elsewhere on the board
/B7: J8.3; also elsewhere on the board
/CLK: J9.4; also elsewhere on the board
/~RST: J9.3; also elsewhere on the board
GND: J8.2; also elsewhere on the board

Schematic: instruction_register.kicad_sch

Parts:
J6: Conn_01x10_Pin; PinHeader_1x10_P2.54mm_Vertical
J7: Conn_01x04_Pin; PinHeader_1x04_P2.54mm_Vertical

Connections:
+5V: J6.1; also elsewhere on the board
/B0: J6.3; also elsewhere on the board
/B1: J6.4; also elsewhere on the board
/B2: J6.5; also elsewhere on the board
/B3: J6.6; also elsewhere on the board
/B4: J6.7; also elsewhere on the board
/B5: J6.8; also elsewhere on the board
/B6: J6.9; also elsewhere on the board
/B7: J6.10; also elsewhere on the board
/CLK: J7.1; also elsewhere on the board
/IR_~READ: J7.2; also elsewhere on the board
/IR_~WRITE: J7.4; also elsewhere on the board
/RST: J7.3; also elsewhere on the board
GND: J6.2; also elsewhere on the board

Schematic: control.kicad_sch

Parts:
J12: Conn_01x07_Pin; PinHeader_1x07_P2.54mm_Vertical
J13, J14: Conn_01x08_Pin; PinHeader_1x08_P2.54mm_Vertical

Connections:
+5V: J12.1; also elsewhere on the board
/ALU_CARRY: J12.3; also elsewhere on the board
/ALU_FI: J14.6; also elsewhere on the board
/ALU_SUB: J14.5; also elsewhere on the board
/ALU_ZERO: J12.4; also elsewhere on the board
/ALU_~WRITE: J14.4; also elsewhere on the board
/AR_~READ: J14.3; also elsewhere on the board
/AR_~WRITE: J14.2; also elsewhere on the board
/BR_~READ: J14.7; also elsewhere on the board
/HALT: J13.6; also elsewhere on the board
/IR_~READ: J13.2; also elsewhere on the board
/IR_~WRITE: J13.1; also elsewhere on the board
/MAR_~EN: J13.5; also elsewhere on the board
/Output_~EN: J14.8; also elsewhere on the board
/PC_CE: J13.8; also elsewhere on the board
/PC_~CO: J14.1; also elsewhere on the board
/PC_~JMP: J13.7; also elsewhere on the board
/RAM_RI: J13.3; also elsewhere on the board
/RAM_~WO: J13.4; also elsewhere on the board
/RST: J12.7; also elsewhere on the board
/~RST: J12.6; also elsewhere on the board
/~CLK: J12.5; also elsewhere on the board
GND: J12.2; also elsewhere on the board

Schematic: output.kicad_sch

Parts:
J21: Conn_01x10_Pin; PinHeader_1x10_P2.54mm_Vertical
J22: Conn_01x04_Pin; PinHeader_1x04_P2.54mm_Vertical

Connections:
+5V: J21.1; also elsewhere on the board
/B0: J21.3; also elsewhere on the board
/B1: J21.4; also elsewhere on the board
/B2: J21.5; also elsewhere on the board
/B3: J21.6; also elsewhere on the board
/B4: J21.7; also elsewhere on the board
/B5: J21.8; also elsewhere on the board
/B6: J21.9; also elsewhere on the board
/B7: J21.10; also elsewhere on the board
/CLK: J22.4; also elsewhere on the board
/Output_~EN: J22.3; also elsewhere on the board
/RST: J22.2; also elsewhere on the board
GND: J21.2, J22.1; also elsewhere on the board


Board: 4 copper layers, 62.2 x 274.1 mm, 50 parts (0 on the bottom side), 42 nets.

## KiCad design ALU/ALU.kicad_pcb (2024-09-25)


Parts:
C1: 0.1uF; C_Disc_D5.0mm_W2.5mm_P2.50mm
D1, D2, D3, D4, D5, D6, D7, D8: LED; LED_D5.0mm
J1: Conn_01x07_Pin; PinHeader_1x07_P2.54mm_Vertical
J2, J3: Conn_01x08_Pin; PinHeader_1x08_P2.54mm_Vertical
J4: Conn_01x10_Pin; PinHeader_1x10_P2.54mm_Vertical
R1, R2, R3, R4, R5, R6, R7, R8: 220; CF_series_Resistors_THT
U1, U2: SN74F86N; 4x_xor
U3: SN74HCT245N; 8x_tristate_transceiver
U4, U5: CD74HCT283E; 4bit_full_adder

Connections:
+5V: C1.1, J4.1, U1.14 (VCC), U2.14 (VCC), U3.1 (DIR), U3.20 (VCC), U4.16 (VCC), U5.16 (VCC); also elsewhere on the board
/A0: J2.1, U4.5 (A0)
/A1: J2.2, U4.3 (A1)
/A2: J2.3, U4.14 (A2)
/A3: J2.4, U4.12 (A3)
/A4: J2.5, U5.5 (A0)
/A5: J2.6, U5.3 (A1)
/A6: J2.7, U5.14 (A2)
/A7: J2.8, U5.12 (A3)
/B0: J3.1, U1.1 (1A)
/B1: J3.2, U1.4 (2A)
/B2: J3.3, U1.12 (4A)
/B3: J3.4, U1.9 (3A)
/B4: J3.5, U2.1 (1A)
/B5: J3.6, U2.4 (2A)
/B6: J3.7, U2.12 (4A)
/B7: J3.8, U2.9 (3A)
/CARRY: J1.6; also elsewhere on the board
/CLK: J1.4; also elsewhere on the board
/Flag enable: J1.5; also elsewhere on the board
/FlagsRegister/Carry: U5.9 (COUT); also elsewhere on the board
/S0: D8.2 (A), U3.2 (A1), U4.4 (S0); also elsewhere on the board
/S1: D7.2 (A), U3.3 (A2), U4.1 (S1); also elsewhere on the board
/S2: D6.2 (A), U3.4 (A3), U4.13 (S2); also elsewhere on the board
/S3: D5.2 (A), U3.5 (A4), U4.10 (S3); also elsewhere on the board
/S4: D4.2 (A), U3.6 (A5), U5.4 (S0); also elsewhere on the board
/S5: D3.2 (A), U3.7 (A6), U5.1 (S1); also elsewhere on the board
/S6: D2.2 (A), U3.8 (A7), U5.13 (S2); also elsewhere on the board
/S7: D1.2 (A), U3.9 (A8), U5.10 (S3); also elsewhere on the board
/Subtract: J1.2, U1.2 (1B), U1.5 (2B), U1.10 (3B), U1.13 (4B), U2.2 (1B), U2.5 (2B), U2.10 (3B), U2.13 (4B), U4.7 (CIN)
/XOR0: U1.3 (1Y), U4.6 (B0)
/XOR1: U1.6 (2Y), U4.2 (B1)
/XOR2: U1.11 (4Y), U4.15 (B2)
/XOR3: U1.8 (3Y), U4.11 (B3)
/XOR4: U2.3 (1Y), U5.6 (B0)
/XOR5: U2.6 (2Y), U5.2 (B1)
/XOR6: U2.11 (4Y), U5.15 (B2)
/XOR7: U2.8 (3Y), U5.11 (B3)
/ZERO: J1.7; also elsewhere on the board
/~RST: J1.3; also elsewhere on the board
/~WRITE: J1.1, U3.19 (*OE)
GND: C1.2, J4.2, R1.2, R2.2, R3.2, R4.2, R5.2, R6.2, R7.2, R8.2, U1.7 (GND), U2.7 (GND), U3.10 (GND), U4.8 (GND), U5.8 (GND); also elsewhere on the board
unnamed: D1.1 (K), R1.1
unnamed: D2.1 (K), R2.1
unnamed: D3.1 (K), R3.1
unnamed: D4.1 (K), R4.1
unnamed: D5.1 (K), R5.1
unnamed: D6.1 (K), R6.1
unnamed: D7.1 (K), R7.1
unnamed: D8.1 (K), R8.1
unnamed: J4.3, U3.11 (B8)
unnamed: J4.4, U3.12 (B7)
unnamed: J4.5, U3.13 (B6)
unnamed: J4.6, U3.14 (B5)
unnamed: J4.7, U3.15 (B4)
unnamed: J4.8, U3.16 (B3)
unnamed: J4.9, U3.17 (B2)
unnamed: J4.10, U3.18 (B1)
unnamed: U4.9 (COUT), U5.7 (CIN)

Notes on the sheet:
Invert B if subtracting


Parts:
D9, D10: LED; LED_D5.0mm
R9, R10: 220; CF_series_Resistors_THT
U6: 4x_and
U7: DIP-14_W7.62mm
U8: Dual D FF; 2x_D_FF

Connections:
+5V: U6.14 (VCC), U7.14 (VCC), U8.4 (*1PRE), U8.10 (*2PRE), U8.14 (VCC); also elsewhere on the board
/CARRY: D9.2 (A), U8.5 (1Q); also elsewhere on the board
/CLK: U6.10 (3B); also elsewhere on the board
/Flag enable: U6.9 (3A); also elsewhere on the board
/FlagsRegister/CLK_Gate: U6.8 (3Y), U8.3 (1CLK), U8.11 (2CLK)
/FlagsRegister/Carry: U8.2 (1D); also elsewhere on the board
/FlagsRegister/all_zero: U6.11 (4Y), U8.12 (2D)
/S0: U7.12 (4B); also elsewhere on the board
/S1: U7.11 (4A); also elsewhere on the board
/S2: U7.2 (1A); also elsewhere on the board
/S3: U7.3 (1B); also elsewhere on the board
/S4: U7.5 (2A); also elsewhere on the board
/S5: U7.6 (2B); also elsewhere on the board
/S6: U7.9 (3B); also elsewhere on the board
/S7: U7.8 (3A); also elsewhere on the board
/ZERO: D10.2 (A), U8.9 (2Q); also elsewhere on the board
/~RST: U8.1 (*1CLR), U8.13 (*2CLR); also elsewhere on the board
GND: R9.2, R10.2, U6.7 (GND), U7.7 (GND), U8.7 (GND); also elsewhere on the board
unnamed: D9.1 (K), R9.1
unnamed: D10.1 (K), R10.1
unnamed: U6.1 (1A), U7.4 (2Y)
unnamed: U6.2 (1B), U7.1 (1Y)
unnamed: U6.3 (1Y), U6.13 (4B)
unnamed: U6.4 (2A), U7.10 (3Y)
unnamed: U6.5 (2B), U7.13 (4Y)
unnamed: U6.6 (2Y), U6.12 (4A)


Board: 2 copper layers, 100.4 x 56.8 mm, 33 parts (0 on the bottom side), 69 nets.

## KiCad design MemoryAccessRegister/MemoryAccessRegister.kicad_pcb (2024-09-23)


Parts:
C1: 0.1uF; C_Disc_D5.0mm_W2.5mm_P2.50mm
D1, D2, D3, D4: LED; LED_D5.0mm
J1: Conn_01x05_Pin; PinHeader_1x05_P2.54mm_Vertical
J2: Conn_01x06_Pin; PinHeader_1x06_P2.54mm_Vertical
J3: Conn_01x03_Pin; PinHeader_1x03_P2.54mm_Vertical
R1, R2, R3, R4: 220; CF_series_Resistors_THT
R5, R6, R7, R8, R9: 1k; CF_series_Resistors_THT
SW1: SW_SPDT; DoubleThrowSwitch
U1: SN74AC14N; 6x_not
U2: CD74HCT258E; 2_to_1_selector
U3: DIP-8
U4: 74LS173; DIP-16_W7.62mm

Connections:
+5V: C1.1, J2.1, R5.1, U1.14 (VCC), U2.16 (VCC), U3.1 (a0), U3.2 (a1), U3.3 (a2), U3.4 (a3), U4.16 (VCC)
/A0: D4.2 (A), J1.2, U1.6 (3Y)
/A1: D3.2 (A), J1.3, U1.4 (2Y)
/A2: D2.2 (A), J1.4, U1.2 (1Y)
/A3: D1.2 (A), J1.5, U1.8 (4Y)
/B0: U2.3 (1B), U4.3 (Q0)
/B1: U2.6 (2B), U4.4 (Q1)
/B2: U2.13 (4B), U4.5 (Q2)
/B3: U2.10 (3B), U4.6 (Q3)
/Bus 0: J2.3, U4.14 (D0)
/Bus 1: J2.4, U4.13 (D1)
/Bus 2: J2.5, U4.12 (D2)
/Bus 3: J2.6, U4.11 (D3)
/CLK: J3.3, U4.7 (Cp)
/Prog 0: R9.1, U2.2 (1A), U3.5 (b3)
/Prog 1: R8.1, U2.5 (2A), U3.6 (b2)
/Prog 2: R7.1, U2.14 (4A), U3.7 (b1)
/Prog 3: R6.1, U2.11 (3A), U3.8 (b0)
/Program: J1.1, R5.2, SW1.1 (A), U2.1 (*A/B)
/RST: J3.2, U4.15 (Mr)
/~A0: U1.5 (3A), U2.4 (1Y)
/~A1: U1.3 (2A), U2.7 (2Y)
/~A2: U1.1 (1A), U2.12 (4Y)
/~A3: U1.9 (4A), U2.9 (3Y)
/~En: J3.1, U4.9 (E1), U4.10 (E2)
GND: C1.2, J2.2, R1.2, R2.2, R3.2, R4.2, R6.2, R7.2, R8.2, R9.2, SW1.2 (B), U1.7 (GND), U2.8 (GND), U2.15 (*G), U4.1 (Oe1), U4.2 (Oe2), U4.8 (GND)
unnamed: D1.1 (K), R1.1
unnamed: D2.1 (K), R2.1
unnamed: D3.1 (K), R3.1
unnamed: D4.1 (K), R4.1


Board: 2 copper layers, 84.3 x 39.2 mm, 22 parts (0 on the bottom side), 30 nets.

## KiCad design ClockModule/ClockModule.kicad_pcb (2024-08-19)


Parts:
J1: Conn_01x05_Pin; PinHeader_1x05_P2.54mm_Vertical

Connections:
+5V: J1.1; also elsewhere on the board
/clk: J1.3; also elsewhere on the board
/halt: J1.5; also elsewhere on the board
/~clk: J1.4; also elsewhere on the board
GND: J1.2; also elsewhere on the board


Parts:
D3: LED; LED_D5.0mm
R7: 1k; CF_series_Resistors_THT
U3: OR; 4x_or
U4: NOT; 6x_not
U5: 4x_and

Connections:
+5V: U3.14 (VCC), U4.14 (VCC), U5.14 (VCC); also elsewhere on the board
/AstableClock/CLK: U5.13 (4B); also elsewhere on the board
/ClockSelect/BistableDebouncingCircuit/Select: U4.1 (1A), U5.12 (4A); also elsewhere on the board
/ClockSelect/Manual_clk: U5.10 (3B); also elsewhere on the board
/clk: D3.2 (A), U4.5 (3A), U5.6 (2Y); also elsewhere on the board
/halt: U4.3 (2A); also elsewhere on the board
/~clk: U4.6 (3Y); also elsewhere on the board
GND: R7.2, U3.7 (GND), U4.7 (GND), U5.7 (GND); also elsewhere on the board
unnamed: D3.1 (K), R7.1
unnamed: U3.1 (1A), U5.11 (4Y)
unnamed: U3.2 (1B), U5.8 (3Y)
unnamed: U3.3 (1Y), U5.5 (2B)
unnamed: U4.2 (1Y), U5.9 (3A)
unnamed: U4.4 (2Y), U5.4 (2A)


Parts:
C4: 0.01uF; C_Disc_D5.0mm_W2.5mm_P2.50mm
C5, C6: 0.1uF; C_Disc_D5.0mm_W2.5mm_P2.50mm
D2: LED; LED_D5.0mm
R4, R6: 1k; CF_series_Resistors_THT
R5: 1M; CF_series_Resistors_THT
S1: TactileSwitch; tactile_switch; MPN B3U-1000P; Digi-Key_PN SW1020CT-ND
U2: LM555xN; DIP-8_W7.62mm

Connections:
+5V: C5.1, R4.2, R5.1, U2.4 (R), U2.8 (VCC); also elsewhere on the board
/ClockSelect/Manual_clk: D2.2 (A), U2.3 (Q); also elsewhere on the board
GND: C4.2, C5.2, C6.2, R6.2, S1.1, U2.1 (GND); also elsewhere on the board
unnamed: D2.1 (K), R6.1
unnamed: C4.1, U2.5 (CV)
unnamed: C6.1, R5.2, U2.6 (THR), U2.7 (DIS)
unnamed: R4.1, S1.4, U2.2 (TR)


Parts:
C1: 0.01uF; C_Disc_D5.0mm_W2.5mm_P2.50mm
C2: 1uF; Cp_2mm_pin_spacing
C3: 0.1uF; C_Disc_D5.0mm_W2.5mm_P2.50mm
D1: LED; LED_D5.0mm
R1, R2, R3: 1k; CF_series_Resistors_THT
RV1: 1M; R_var
U1: LM555xN; DIP-8_W7.62mm

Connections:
+5V: C3.1, R1.1, U1.4 (R), U1.8 (VCC); also elsewhere on the board
/AstableClock/CLK: D1.2 (A), U1.3 (Q); also elsewhere on the board
GND: C1.2, C2.2, C3.2, R3.2, U1.1 (GND); also elsewhere on the board
unnamed: D1.1 (K), R3.1
unnamed: R2.2, RV1.2
unnamed: C1.1, U1.5 (CV)
unnamed: R1.2, R2.1, U1.7 (DIS)
unnamed: C2.1, RV1.1, U1.2 (TR), U1.6 (THR)


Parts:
C7: 0.01uF; C_Disc_D5.0mm_W2.5mm_P2.50mm
C8: 0.1uF; C_Disc_D5.0mm_W2.5mm_P2.50mm
R8, R9: 1k; CF_series_Resistors_THT
SW1: SW_SPDT; DoubleThrowSwitch
U6: LM555xN; DIP-8_W7.62mm

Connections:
+5V: C8.1, R8.2, R9.2, U6.8 (VCC); also elsewhere on the board
/ClockSelect/BistableDebouncingCircuit/Select: U6.3 (Q); also elsewhere on the board
GND: C7.2, C8.2, SW1.2 (B), U6.1 (GND), U6.6 (THR); also elsewhere on the board
unnamed: R8.1, SW1.1 (A), U6.2 (TR)
unnamed: R9.1, SW1.3 (C), U6.4 (R)
unnamed: C7.1, U6.5 (CV)


Board: 2 copper layers, 81.5 x 52.5 mm, 30 parts (0 on the bottom side), 26 nets.

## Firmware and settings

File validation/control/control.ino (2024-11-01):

/* TEST PLAN
 *
 * 1) Test each instruction
 *  a) Check each step though the microcode cycle
 *  b) Check with all flag states
 */
#define DEBUG false

#define CLK_HALF_PERIOD_MS 20

// Control output pins
#define I_WO_N   37
#define I_RI_N   35
#define RAM_RI   33
#define RAM_WO_N 31
#define MAR_EN_N 29
#define CLK_HALT 27
#define PC_JMP_N 25
#define PC_EN    23

#define PC_CO_N  36
#define A_WO_N   34
#define A_RI_N   32
#define ALU_WO_N 30
#define ALU_SUB  28
#define ALU_FI   26
#define B_RI_N   24
#define OUT_EN_N 22

#define RST 41

// Control input pins
#define ALU_CARRY 47
#define ALU_ZERO  45
#define CLK       43
#define INS_SIZE  4
const int instruction[INS_SIZE] = {44, 42, 40, 38};

// Signal bit mapping
#define IO   0x8000
#define II   0x4000
#define RI   0x2000
#define RO   0x1000
#define MI   0x0800
#define HLT  0x0400
#define JMP  0x0200
#define PCE  0x0100
#define PCO  0x0080
#define AO   0x0040
#define AI   0x0020
#define ALUO 0x0010
#define SUB  0x0008
#define FI   0x0004
#define BI   0x0002
#define OUT  0x0001

/* Basic utility functions */
void print_bin8(int n) {
  for(int i = 7; i >= 0; i--) {
    Serial.print((n>>i)&1);
  }
}

void print_signals(uint16_t signals) {
  if (signals & IO)   {Serial.print("IR OUT, ");}
  if (signals & II)   {Serial.print("IR IN, ");}
  if (signals & RI)   {Serial.print("RAM IN, ");}
  if (signals & RO)   {Serial.print("RAM OUT, ");}
  if (signals & MI)   {Serial.print("MAR EN, ");}
  if (signals & HLT)  {Serial.print("CLK HLT, ");}
  if (signals & JMP)  {Serial.print("JMP, ");}
  if (signals & PCE)  {Serial.print("PC EN, ");}
  
  if (signals & PCO)  {Serial.print("PC OUT, ");}
  if (signals & AO)   {Serial.print("AR OUT, ");}
  if (signals & AI)   {Serial.print("AR IN, ");}
  if (signals & ALUO) {Serial.print("ALU OUT, ");}
  if (signals & SUB)  {Serial.print("ALU SUB, ");}
  if (signals & FI)   {Serial.print("ALU FI, ");}
  if (signals & BI)   {Serial.print("BR IN, ");}
  if (signals & OUT)  {Serial.print("OUT EN, ");}
}

bool test_equal(int value, int expected, char* test) {
  if (value == expected) {
    if (DEBUG == false) {return true;}
    Serial.print("Pass  (");
    Serial.print(test);
    Serial.print("): Expected ");
    Serial.print(expected);
    Serial.print(" (");
    print_signals(expected);
    Serial.print(")");
    Serial.print(" - Actual ");
    Serial.print(value);
    Serial.print(" (");
    print_signals(value);
    Serial.print(")");
    Serial.println();
    return true;
  } else {
    Serial.print("ERROR (");
    Serial.print(test);
    Serial.print("): Expected ");
    Serial.print(expected);
    Serial.print(" (");
    print_signals(expected);
    Serial.print(")");
    Serial.print(" - Actual ");
    Serial.print(value);
    Serial.print(" (");
    print_signals(value);
    Serial.print(")");
    Serial.println();
    return false;
  }
}

void clock_pulse() {
  digitalWrite(CLK, HIGH);
  delay(CLK_HALF_PERIOD_MS);
  digitalWrite(CLK, LOW);
  delay(CLK_HALF_PERIOD_MS);
}

uint16_t read_control_signals() {
  uint16_t state = 0;
  state += !digitalRead(I_WO_N);
  state <<= 1;
  state += !digitalRead(I_RI_N);
  state <<= 1;
  state += digitalRead(RAM_RI);
  state <<= 1;
  state += !digitalRead(RAM_WO_N);
  state <<= 1;
  state += !digitalRead(MAR_EN_N);
  state <<= 1;
  state += digitalRead(CLK_HALT);
  state <<= 1;
  state += !digitalRead(PC_JMP_N);
  state <<= 1;
  state += digitalRead(PC_EN);
  state <<= 1;
  
  state += !digitalRead(PC_CO_N);
  state <<= 1;
  state += !digitalRead(A_WO_N);
  state <<= 1;
  state += !digitalRead(A_RI_N);
  state <<= 1;
  state += !digitalRead(ALU_WO_N);
  state <<= 1;
  state += digitalRead(ALU_SUB);
  state <<= 1;
  state += digitalRead(ALU_FI);
  state <<= 1;
  state += !digitalRead(B_RI_N);
  state <<= 1;
  state += !digitalRead(OUT_EN_N);

  return state;
}

void set_instruction(uint8_t ins) {
  for (int i=0; i<INS_SIZE; i++) {
    digitalWrite(instruction[i], (ins>>i)&1);
  }
}

// Get the user to press the reset button to reset the microcode timer
void reset_timer() {
  Serial.println("Please press reset");
  while(digitalRead(RST) == LOW) {}
  clock_pulse();
  while(digitalRead(RST) == HIGH) {}
}

/* Test functions */
int test_ins(uint8_t ins, uint16_t code[6], char *test_name) {
  int pass = 0;
  set_instruction(ins);
  for (uint8_t flags=0; flags<=3; flags++) {
    digitalWrite(ALU_CARRY, flags>>1);
    digitalWrite(ALU_ZERO, flags&1);
    for (int i=0; i<6; i++) {
      char buf[100];
      sprintf(buf, "%s (0x%x) T=%d (C=%d,Z=%d)", test_name, ins, i, (flags>>1)&1, flags&1);
      pass += test_equal(read_control_signals(), code[i], buf);
      clock_pulse();
    }
  }
  return pass;
}

int test_jmpc() {
  int pass = 0;
  uint16_t code_carry_set[6] = {MI|PCO, RO|II|PCE, IO|JMP, 0, 0, 0};
  uint16_t code_carry_not_set[6] = {MI|PCO, RO|II|PCE, 0, 0, 0, 0};
  set_instruction(0b0111);
  for (uint8_t flags=0; flags<=3; flags++) {
    digitalWrite(ALU_CARRY, flags>>1);
    digitalWrite(ALU_ZERO, flags&1);
    for (int i=0; i<6; i++) {
      char buf[100];
      sprintf(buf, "Jump Carry (0x0111) T=%d (C=%d,Z=%d)", i, (flags>>1)&1, flags&1);
      if (flags>>1) {
        pass += test_equal(read_control_signals(), code_carry_set[i], buf);
      } else {
        pass += test_equal(read_control_signals(), code_carry_not_set[i], buf);
      }
      clock_pulse();
    }
  }
  return pass;
}

int test_jmpz() {
  int pass = 0;
  uint16_t code_carry_set[6] = {MI|PCO, RO|II|PCE, IO|JMP, 0, 0, 0};
  uint16_t code_carry_not_set[6] = {MI|PCO, RO|II|PCE, 0, 0, 0, 0};
  set_instruction(0b1000);
  for (uint8_t flags=0; flags<=3; flags++) {
    digitalWrite(ALU_CARRY, flags>>1);
    digitalWrite(ALU_ZERO, flags&1);
    for (int i=0; i<6; i++) {
      char buf[100];
      sprintf(buf, "Jump Zero (0x1000) T=%d (C=%d,Z=%d)", i, (flags>>1)&1, flags&1);
      if (flags&1) {
        pass += test_equal(read_control_signals(), code_carry_set[i], buf);
      } else {
        pass += test_equal(read_control_signals(), code_carry_not_set[i], buf);
      }
      clock_pulse();
    }
  }
  return pass;
}

void setup() {
  Serial.begin(9600);

  /* Pin setup */
  pinMode(ALU_CARRY, OUTPUT);
  digitalWrite(ALU_CARRY, LOW);
  pinMode(ALU_ZERO, OUTPUT);
  digitalWrite(ALU_ZERO, LOW);
  pinMode(CLK, OUTPUT);
  digitalWrite(CLK, LOW);
  for (int ins=0; ins<pow(2, INS_SIZE); ins++) {
    pinMode(ins, OUTPUT);
    digitalWrite(ins, LOW);
  }

  pinMode(RST, INPUT);

  pinMode(I_WO_N, INPUT);
  pinMode(I_RI_N, INPUT);
  pinMode(RAM_RI, INPUT);
  pinMode(RAM_WO_N, INPUT);
  pinMode(MAR_EN_N, INPUT);
  pinMode(CLK_HALT, INPUT);
  pinMode(PC_JMP_N, INPUT);
  pinMode(PC_EN, INPUT);
  pinMode(PC_CO_N, INPUT);
  pinMode(A_WO_N, INPUT);
  pinMode(A_RI_N, INPUT);
  pinMode(ALU_WO_N, INPUT);
  pinMode(ALU_SUB, INPUT);
  pinMode(ALU_FI, INPUT);
  pinMode(B_RI_N, INPUT);
  pinMode(OUT_EN_N, INPUT);

  reset_timer();
  
  /* Tests */
  uint16_t code[][6] = {
    {MI|PCO, RO|II|PCE, 0, 0, 0, 0}, // No OP
    {MI|PCO, RO|II|PCE, IO|MI, RO|AI, 0, 0}, // LDA
    {MI|PCO, RO|II|PCE, IO|MI, RO|BI, ALUO|FI|AI, 0}, // ADD
    {MI|PCO, RO|II|PCE, IO|MI, RO|BI, ALUO|SUB|FI|AI, 0}, // SUB
    {MI|PCO, RO|II|PCE, IO|MI, AO|RI, 0, 0}, // STA
    {MI|PCO, RO|II|PCE, IO|AI, 0, 0, 0}, // LDI
    {MI|PCO, RO|II|PCE, IO|JMP, 0, 0, 0}, // JMP
    {MI|PCO, RO|II|PCE, AO|OUT, 0, 0, 0}, // OUT
    {MI|PCO, RO|II|PCE, HLT, 0, 0, 0} // HALT
  };
  int noop = test_ins(0, code[0], "No OP");
  int lda = test_ins(1, code[1], "Load A");
  int add = test_ins(2, code[2], "Add");
  int sub = test_ins(3, code[3], "Subtract");
  int sta = test_ins(4, code[4], "Store A");
  int ldi = test_ins(5, code[5], "Load imediate");
  int jmp = test_ins(6, code[6], "Jump");
  int out = test_ins(14, code[7], "Output");
  int hlt = test_ins(15, code[8], "Halt");
  int jmpc = test_jmpc();
  int jmpz = test_jmpz();

  Serial.print("No OP:\t\t");
  Serial.print(noop);
  Serial.println("/24");

  Serial.print("Load A:\t\t");
  Serial.print(lda);
  Serial.println("/24");

  Serial.print("Add:\t\t");
  Serial.print(add);
  Serial.println("/24");

  Serial.print("Subtract:\t");
  Serial.print(sub);
  Serial.println("/24");

  Serial.print("Store A:\t");
  Serial.print(sta);
  Serial.println("/24");

  Serial.print("Load Imediate:\t");
  Serial.print(ldi);
  Serial.println("/24");

  Serial.print("Jump:\t\t");
  Serial.print(jmp);
  Serial.println("/24");

  Serial.print("Output:\t\t");
  Serial.print(out);
  Serial.println("/24");

  Serial.print("Halt:\t\t");
  Serial.print(hlt);
  Serial.println("/24");

  Serial.print("Jump carry:\t");
  Serial.print(jmpc);
  Serial.println("/24");

  Serial.print("Jump zero:\t");
  Serial.print(jmpz);
  Serial.println("/24");
  
  Serial.println();
}

void loop() {}

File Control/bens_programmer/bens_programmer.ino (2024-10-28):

/**
 * This sketch programs the microcode EEPROMs for the 8-bit breadboard computer
 * It includes support for a flags register with carry and zero flags
 * See this video for more: https://youtu.be/Zg1NdPKoosU
 */
#define SHIFT_DATA 2
#define SHIFT_CLK 3
#define SHIFT_LATCH 4
#define EEPROM_D0 5
#define EEPROM_D7 12
#define WRITE_EN 13

#define MI  0b1000000000000000
#define RO  0b0100000000000000
#define RI  0b0010000000000000
#define II  0b0001000000000000
#define IO  0b0000100000000000
#define EO  0b0000010000000000
#define BI  0b0000001000000000
#define OI  0b0000000100000000

#define AO  0b0000000010000000
#define AI  0b0000000001000000
#define CE  0b0000000000100000
#define HLT 0b0000000000010000
#define J   0b0000000000001000
#define FI  0b0000000000000100
#define SU  0b0000000000000010
#define CO  0b0000000000000001

#define FLAGS_Z0C0 0
#define FLAGS_Z0C1 1
#define FLAGS_Z1C0 2
#define FLAGS_Z1C1 3

#define JC  0b0111
#define JZ  0b1000

uint16_t UCODE_TEMPLATE[16][8] = {
  { MI|CO,  RO|II|CE,  0,      0,      0,           0, 0, 0 },   // 0000 - NOP
  { MI|CO,  RO|II|CE,  IO|MI,  RO|AI,  0,           0, 0, 0 },   // 0001 - LDA
  { MI|CO,  RO|II|CE,  IO|MI,  RO|BI,  EO|AI|FI,    0, 0, 0 },   // 0010 - ADD
  { MI|CO,  RO|II|CE,  IO|MI,  RO|BI,  EO|AI|SU|FI, 0, 0, 0 },   // 0011 - SUB
  { MI|CO,  RO|II|CE,  IO|MI,  AO|RI,  0,           0, 0, 0 },   // 0100 - STA
  { MI|CO,  RO|II|CE,  IO|AI,  0,      0,           0, 0, 0 },   // 0101 - LDI
  { MI|CO,  RO|II|CE,  IO|J,   0,      0,           0, 0, 0 },   // 0110 - JMP
  { MI|CO,  RO|II|CE,  0,      0,      0,           0, 0, 0 },   // 0111 - JC
  { MI|CO,  RO|II|CE,  0,      0,      0,           0, 0, 0 },   // 1000 - JZ
  { MI|CO,  RO|II|CE,  0,      0,      0,           0, 0, 0 },   // 1001
  { MI|CO,  RO|II|CE,  0,      0,      0,           0, 0, 0 },   // 1010
  { MI|CO,  RO|II|CE,  0,      0,      0,           0, 0, 0 },   // 1011
  { MI|CO,  RO|II|CE,  0,      0,      0,           0, 0, 0 },   // 1100
  { MI|CO,  RO|II|CE,  0,      0,      0,           0, 0, 0 },   // 1101
  { MI|CO,  RO|II|CE,  AO|OI,  0,      0,           0, 0, 0 },   // 1110 - OUT
  { MI|CO,  RO|II|CE,  HLT,    0,      0,           0, 0, 0 },   // 1111 - HLT
};

uint16_t ucode[4][16][8];

void initUCode() {
  // ZF = 0, CF = 0
  memcpy(ucode[FLAGS_Z0C0], UCODE_TEMPLATE, sizeof(UCODE_TEMPLATE));

  // ZF = 0, CF = 1
  memcpy(ucode[FLAGS_Z0C1], UCODE_TEMPLATE, sizeof(UCODE_TEMPLATE));
  ucode[FLAGS_Z0C1][JC][2] = IO|J;

  // ZF = 1, CF = 0
  memcpy(ucode[FLAGS_Z1C0], UCODE_TEMPLATE, sizeof(UCODE_TEMPLATE));
  ucode[FLAGS_Z1C0][JZ][2] = IO|J;

  // ZF = 1, CF = 1
  memcpy(ucode[FLAGS_Z1C1], UCODE_TEMPLATE, sizeof(UCODE_TEMPLATE));
  ucode[FLAGS_Z1C1][JC][2] = IO|J;
  ucode[FLAGS_Z1C1][JZ][2] = IO|J;
}

/*
 * Output the address bits and outputEnable signal using shift registers.
 */
void setAddress(int address, bool outputEnable) {
  shiftOut(SHIFT_DATA, SHIFT_CLK, MSBFIRST, (address >> 8) | (outputEnable ? 0x00 : 0x80));
  shiftOut(SHIFT_DATA, SHIFT_CLK, MSBFIRST, address);

  digitalWrite(SHIFT_LATCH, LOW);
  digitalWrite(SHIFT_LATCH, HIGH);
  digitalWrite(SHIFT_LATCH, LOW);
}


/*
 * Read a byte from the EEPROM at the specified address.
 */
byte readEEPROM(int address) {
  for (int pin = EEPROM_D0; pin <= EEPROM_D7; pin += 1) {
    pinMode(pin, INPUT);
  }
  setAddress(address, /*outputEnable*/ true);

  byte data = 0;
  for (int pin = EEPROM_D7; pin >= EEPROM_D0; pin -= 1) {
    data = (data << 1) + digitalRead(pin);
  }
  return data;
}


volatile int failures = 0;
/*
 * Write a byte to the EEPROM at the specified address.
 */
void writeEEPROM(int address, byte data) {
  Serial.print("Writing address 0x");
  Serial.print(address, HEX);
  Serial.print(" (0x");
  Serial.print(data, HEX);
  Serial.println(")");
  int wait = 10;
  uint8_t r;
  uint8_t d = data;
  do {
    setAddress(address, /*outputEnable*/ false);
    for (int pin = EEPROM_D0; pin <= EEPROM_D7; pin += 1) {
      pinMode(pin, OUTPUT);
    }
  
    for (int pin = EEPROM_D0; pin <= EEPROM_D7; pin += 1) {
      digitalWrite(pin, data & 1);
      data = data >> 1;
    }
    delay(wait);
    digitalWrite(WRITE_EN, LOW);
    delayMicroseconds(1);
    digitalWrite(WRITE_EN, HIGH);
    delay(wait);
    readEEPROM(address);
    r = readEEPROM(address);
    Serial.print(r, HEX);
    Serial.print(' ');
    Serial.println(d);
    Serial.print("Waiting "); Serial.println(wait);
    wait *= 1.5;
    if (wait > 4000) {
      failures++;
      break;
    }
  } while (d != r);
}


/*
 * Read the contents of the EEPROM and print them to the serial monitor.
 */
void printContents(int start, int length) {
  for (int base = start; base < length; base += 16) {
    byte data[16];
    for (int offset = 0; offset <= 15; offset += 1) {
      data[offset] = readEEPROM(base + offset);
    }

    char buf[80];
    sprintf(buf, "%03x:  %02x %02x %02x %02x %02x %02x %02x %02x   %02x %02x %02x %02x %02x %02x %02x %02x",
            base, data[0], data[1], data[2], data[3], data[4], data[5], data[6], data[7],
            data[8], data[9], data[10], data[11], data[12], data[13], data[14], data[15]);

    Serial.println(buf);
  }
}


void setup() {
  // put your setup code here, to run once:
  initUCode();

  pinMode(SHIFT_DATA, OUTPUT);
  pinMode(SHIFT_CLK, OUTPUT);
  pinMode(SHIFT_LATCH, OUTPUT);
  digitalWrite(WRITE_EN, HIGH);
  pinMode(WRITE_EN, OUTPUT);
  Serial.begin(57600);

  // Program data bytes
  Serial.print("Programming EEPROM");

  // Program the 8 high-order bits of microcode into the first 128 bytes of EEPROM
  for (int address = 0; address < 1024; address += 1) {
    int flags       = (address & 0b1100000000) >> 8;
    int byte_sel    = (address & 0b0010000000) >> 7;
    int instruction = (address & 0b0001111000) >> 3;
    int step        = (address & 0b0000000111);

    if (byte_sel) {
      writeEEPROM(address, ucode[flags][instruction][step]);
    } else {
      writeEEPROM(address, ucode[flags][instruction][step] >> 8);
    }

    if (address % 64 == 0) {
      Serial.print(".");
    }
  }

  Serial.println(" done");


  // Read and print out the contents of the EERPROM
  Serial.println("Reading EEPROM");
  printContents(0, 1024);

  Serial.println();
  Serial.print("Failed to write: ");
  Serial.println(failures);
}


void loop() {
  // put your main code here, to run repeatedly:

}

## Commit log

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2024-07-22 Clock module created and layedout on PCB
    [ClockModule.kicad_pcb, ClockModule.kicad_sch, astable_clock.kicad_sch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]
2024-07-22 Initial work on registers. Should be usable for both A and B, but unsure about instruction register. May need pins to come out the other side and only need 4 of the bits
    [Registers.kicad_pcb, Registers.kicad_sch]
2024-07-22 Initial work on bus. Clock, power, and bus pins from clock and registers connected in schematic
    [A_register.kicad_sch, bus.kicad_pcb, bus.kicad_sch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]
2024-07-22 ALU schematic setup without zero or carry output flags
    [ALU.kicad_pcb, ALU.kicad_sch]
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2024-07-22 ALU routed on PCB
    [ALU.kicad_pcb, ALU.kicad_sch]
2024-07-22 Added the ALU to the bus schematic
    [alu.kicad_sch, bus.kicad_sch]
2024-07-22 Switched LEDs to MSB first. Added label to board.
    [ALU.kicad_pcb]
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2024-07-25 Added atmega schematic for RAM emulation
    [RAM.kicad_pcb, RAM.kicad_sch, atmega_ram_emulator.kicad_sch]
2024-07-25 RAM input selection schematic complete
    [RAM.kicad_sch, atmega_ram_emulator.kicad_sch]
2024-07-25 RAM output connected to bus
    [RAM.kicad_sch, atmega_ram_emulator.kicad_sch]
2024-07-25 Added logic to select between program or run mode signals
    [RAM.kicad_sch, atmega_ram_emulator.kicad_sch]
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2024-07-25 Assigned footprints to all RAM components except crystal. No datasheet so waiting for delivery to hopefully get more detail or measure
    [RAM.kicad_sch, atmega_ram_emulator.kicad_sch]
2024-07-26 RAM module layout complete except footprint for crystal
    [RAM.kicad_pcb, RAM.kicad_sch, atmega_ram_emulator.kicad_sch]
2024-07-26 Memory address register schematic and PCB complete
    [MemoryAccessRegister.kicad_pcb, MemoryAccessRegister.kicad_sch]
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2024-07-29 Fixed LED and pin footprints for MAR and cleaned up the layout
    [MemoryAccessRegister.kicad_pcb, MemoryAccessRegister.kicad_sch]
2024-07-29 Fixed LED and pin footprints for MAR and cleaned up the layout
    Fixed LED and pin footprints for MAR and cleaned up the layout
    [MemoryAccessRegister.kicad_pcb, MemoryAccessRegister.kicad_sch]
2024-08-03 Inital output design. Need to test to validate design works
    [7_segment_shift_register.kicad_sch, Output.kicad_pcb, Output.kicad_sch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]
2024-08-03 Addded ALU flags register and laided out the PCB again
    [ALU.kicad_pcb, ALU.kicad_sch, flags_register.kicad_sch]
2024-08-04 4x NOR pinout was wrong. Updated with correct pinout. Fixed 2x D flip-flop references
    [ALU.kicad_pcb, ALU.kicad_sch, flags_register.kicad_sch]
2024-08-10 Fixed NOR schematic labeled as OR in ALU
    [ALU.kicad_pcb, flags_register.kicad_sch]
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2024-08-12 Fixed push button always shorting
    [ClockModule.kicad_pcb, manual_clock.kicad_sch]
2024-08-12 Fixed double throw switch footprint
    [ClockModule.kicad_pcb]
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2024-08-19 Switch pull up resistor was connected to wrong pin. Connected to switch now
    [ClockModule.kicad_pcb, bistable_debouncing_circuit.kicad_sch]
2024-08-29 Finished routing for registers. Silkscreen and PCB shape needs to be finalized.
    [Registers.kicad_pcb, Registers.kicad_sch]
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2024-08-30 Fixed misrouted bus connections to MUX. MUX is inverting so adde inverterto invert back. Slide switch should be conencted to power and pulled to ground. Breadboard validated.
    [ALU.kicad_pcb, MemoryAccessRegister.kicad_pcb, MemoryAccessRegister.kicad_sch]
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2024-08-31 Minor silkscreen fixes
    [MemoryAccessRegister.kicad_pcb]
2024-09-01 Added more wiggle room to the double throw switch footprint. PCBs ordered for MAR/ALU/Registers
    [MemoryAccessRegister.kicad_pcb, Registers.kicad_pcb]
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2024-09-06 Updated bus schematics with pinout of MAR/ALU/Registers on PCBs ordered
    [MAR.kicad_sch, alu.kicad_sch, bus.kicad_sch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]
2024-09-12 Fixed registers silkscreen errors
    [Registers.kicad_pcb]
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2024-09-16 Manufacturer footprint and data sheet seem to be wrong for the mux. Input for bits 3 and 4 are swapped.
    [MemoryAccessRegister.kicad_pcb, MemoryAccessRegister.kicad_sch]
2024-09-18 Updated RAM push button to use pins that aren't shorted together
    [RAM.kicad_pcb, RAM.kicad_sch, atmega_ram_emulator.kicad_sch]
2024-09-18 Updated RAM pin headers to 2.54mm and correct assignment
    [RAM.kicad_pcb, RAM.kicad_sch, atmega_ram_emulator.kicad_sch]
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2024-09-20 Fixed incorrect MUX inputs on RAM
    [RAM.kicad_pcb, RAM.kicad_sch, atmega_ram_emulator.kicad_sch]
2024-09-20 Simulation of the clock edge detector to verify it works because the LEDs/arduino/my eyes aren't fast enough
    [sim_test.kicad_pcb, sim_test.kicad_sch]
2024-09-23 Swapped Run and Prog silk screen to match reality
    [MemoryAccessRegister.kicad_pcb]
2024-09-25 Forgot Flags register input enable. Passing clock though spare AND gate with new input Flag In input to create equvilant
    [ALU.kicad_pcb, ALU.kicad_sch, flags_register.kicad_sch]
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2024-10-02 Added silkscreen labels to control LEDs. And other minor silkscreen updates
    [Control.kicad_pcb]
2024-10-02 Added edge cuts and mounting holes to control PCB
    [Control.kicad_pcb]
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2024-10-03 Updated microcode timer LEDs to 1 hot signal instead of binary counter
    [Control.kicad_pcb, Control.kicad_sch, micro_code_timer.kicad_sch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]
2024-10-04 Registers appear to be working correctly until internal state pins are connected to arduino. Without connections all tests are passing using the LEDs visually, but connecting seems to interfere with 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
    [A_regsiter_test.ino]
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2024-10-04 MAR validated in run mode. Need to replace broken slide switches for program mode.
    [mar_test.ino]
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2024-10-07 Updated bus schematic control pins and added spare bus connection
    [A_register.kicad_sch, alu.kicad_sch, bus.kicad_sch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]
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2024-10-07 Updated output to use 2 4-bit registers instead of 1 8-bit because that's what I have. No longer need the AND for clk enable as registers have an enable pin. Enable is now active low. Reset is now ac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
    [7_segment_shift_register.kicad_sch, Output.kicad_sch, mcu.kicad_sch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]
2024-10-07 Updated output to use eeprom and timing circuit instead of atmega a shift registers
    [Output.kicad_sch, display_timer.kicad_sch]
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2024-10-07 Fixed digit order and segments for some digits
    [EEPROM_programmer.ino]
2024-10-07 Added silkscreen to IO and added edge cuts and mounting points
    [Output.kicad_pcb, display_timer.kicad_sch]
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2024-10-08 Made atmega RAM emulators invert the data, because the selector is inverting it on the way in. Also fixed bug using WE pin inverted.
    [RAM.kicad_sch]
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2024-10-09 Updated bus schmatic pins to match final layouts
    [A_register.kicad_sch, MAR.kicad_sch, alu.kicad_sch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]
2024-10-09 Output enable should be active low so I updated control to pass it through an inverter
    [Control.kicad_pcb, Control.kicad_sch, bus.kicad_sch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]
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2024-10-09 Fixed mismatched RAM labels
    [ram.kicad_sch, spare.kicad_sch]
2024-10-09 Added pins to bus PCB. Oh boy it's going to be long
    [bus.kicad_pcb, spare.kicad_sch]
2024-10-09 Added an extra power option if I can't solder the USB header
    [bus.kicad_pcb, usb_c_power.kicad_sch]
2024-10-10 Aligned bus pins with where they will fit when connected to the other modules
    [bus.kicad_pcb]
2024-10-10 Bus fully routed. Minor edits to control to match bus
    [Control.kicad_pcb, Control.kicad_sch, bus.kicad_pcb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]
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2024-10-15 EEPROM programmer setup for programming according to my PCB layout
    [contol_logic.ods]
2024-10-16 Flag reset tests added and passing. All ALU tests passing
    [alu_test.ino]
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2024-10-19 Connected unused control pins (B out/Output 2's Complement) to disabled values instead of floating
    [bus.kicad_pcb, bus.kicad_sch]
2024-10-20 Ouput bus was labeled incorectly. Labels fixed on output. Labels and connections fixed on bus
    [Output.kicad_pcb, bus.kicad_pcb, output.kicad_sch]
2024-10-21 Demux enable is active low. Should have been connected to ground not power
    [Output.kicad_pcb, display_timer.kicad_sch]
2024-10-23 Added a pull up resistor to the programming button
    [RAM.kicad_pcb, RAM.kicad_sch]
2024-10-23 Fixed barely connected power wire
    [RAM.kicad_pcb]
2024-10-23 Atmega uses interrupts instead of polling to monitor for write signal to prevent missing the signal
    [atmega_ram_emulator.ino]
2024-10-31 RAM write/read to all values test written. Currently failing random tests. I think there are 2 issues; 1 - connectivity of the atmegas in the header pins doesn't seem to be 100% all the time, 2 - the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
    [ram.ino]
2024-10-31 Output reset test passing
    [output.ino]
2024-10-31 Control tests for all non-conditional instructions. Currently failing randomly-ish. I think the signal integreity from the instruction register is not great into the EEPROM headers
    [control.ino]
2024-11-01 Control reset signals were inverted
    [Control.kicad_pcb, reset.kicad_sch]
2024-11-01 Added pulling resistors to unused pins from bus. (Output 2s comp & B reg write out)
    [Output.kicad_pcb, Output.kicad_sch, Registers.kicad_pcb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]
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
